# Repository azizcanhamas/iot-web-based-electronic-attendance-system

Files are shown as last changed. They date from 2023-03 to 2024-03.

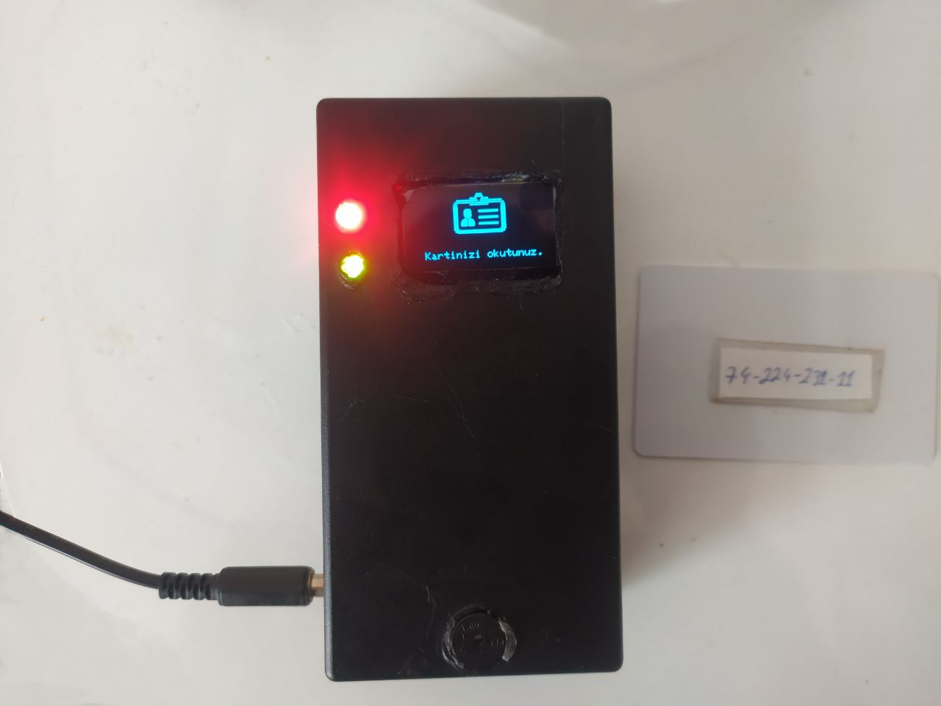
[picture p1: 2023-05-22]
report/interim_report/images/outer.png

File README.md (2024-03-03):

# IoT & Web Based Electronic Attendance System
Firat University Computer Engineering graduation project. 

# YouTube Video
https://www.youtube.com/watch?v=eulfiEd6Mw8

# Login screen.
login

# Student panel for attendance tracking.
student

# Admin panel for system management.
admin

# Circuit diagram for device.
circuit

# Database diagram.
db

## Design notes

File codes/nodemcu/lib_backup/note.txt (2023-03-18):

* Klasörler "Documents -> Arduino -> libraries" 
dizinine kopyalanmalıdır.

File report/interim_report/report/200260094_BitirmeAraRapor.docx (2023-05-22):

T.C.

FIRAT ÜNİVERSİTESİ

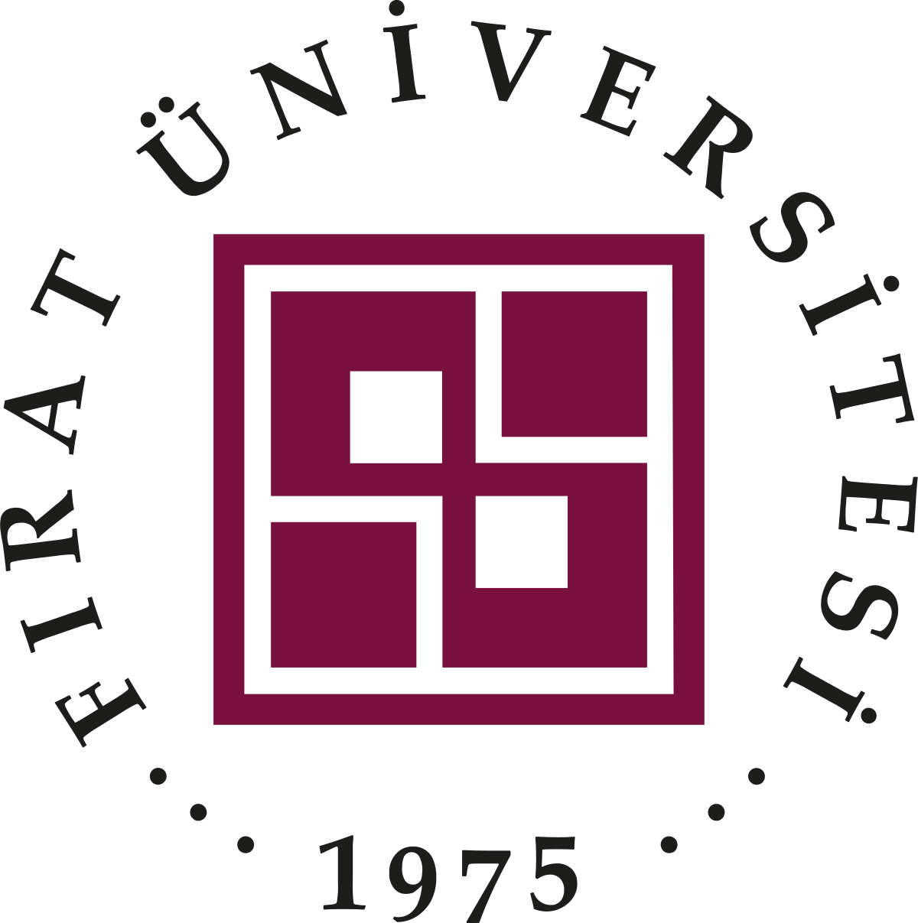
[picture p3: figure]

IoT TABANLI

ELEKTRONİK YOKLAMA SİSTEMİ

BİTİRME PROJESİ

ARA RAPORU

Aziz Can HAMAŞOĞLU

Danışman: Dr. Öğr. Üyesi Erkan DUMAN

# İÇİNDEKİLER

# GİRİŞ

Fırat Üniversitesi Bilgisayar Mühendisliği Lisans programından mezun olabilme şartı olan Bitirme Projesi dersi için “IoT Tabanlı Elektronik Yoklama Sistemi” konulu proje bahar yarıyılının başında proje konusu olarak seçilmişti. Bu raporda projenin hangi aşamaya getirildiği, hangi özelliklerin kazandırıldığı, bu özelliklerin geliştirilmesi için hangi teknolojilerin kullanıldığı, projede hangi eksikliklerin mevcut olduğu ve bu eksikliklerin nasıl giderileceğine değinilmiştir. Detaylı teknik açıklamalara yazılması planlanan bitirme tezinde değinilecektir.

## 1. Elektronik Yoklama Süreci

Şekil 1’de elektronik yoklama sürecinin nasıl gerçekleştirildiği adım adım gösterilmiştir. 1 numaralı adımda; derse katılan öğrenci sistemde kendisine tanımlanan RFID kartını cihaza okutmaktadır. Cihaz tarafından okutulan RFID kartının değerleri okunmaktadır. Elde edilen bu değerler kurumun Wi-Fi ağına bağlı olan mikrodenetleyici kart ile sunucuya API servisleri üzerinden gönderilmektedir. Sunucu, hangi IoT cihazının istekte bulunduğu, gelen RFID bilgisi ile öğrencinin kayıtlı olup olmadığı, ilgili dersi alıp almadığı gibi kompleks kontrolleri veritabanına bağlanarak gerçekleştirmektedir. Gerçekleştirilen bu kontroller sonucunda öğrenciye “Yoklama Alındı!”, “Kart Tanımlı Değil!”, “Bu Derse Kayıtlı Değilsiniz!” gibi bilgilendirici mesajlar ekranda gösterilmektedir.

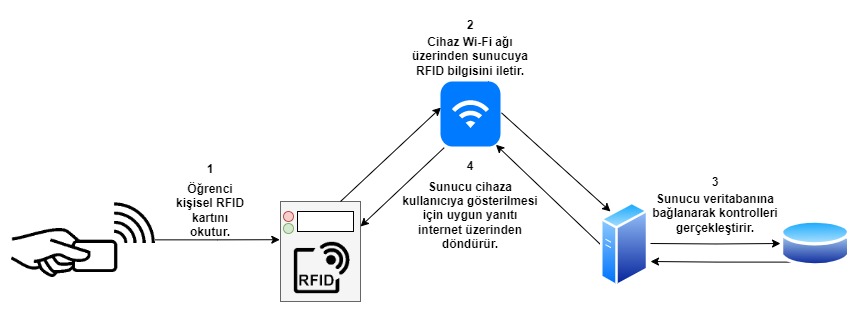
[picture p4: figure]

Şekil 1: Elektronik yoklama sürecini gösterir akış diyagramı

## 2. Donanım Kısmının Gerçekleştirilmesi

Öğrencilerin kullanacak olduğu RFID kartlarının okunabilmesi, bu kartlardan okunan değerlerin sunucuya internet üzerinden iletilebilmesi ve öğrenciye bilgilendirme mesajlarının gösterilebilmesi için bir donanım çözümü geliştirilmiştir. Bu donanım çözümü için geliştirilen devre diyagramına Şekil 2’de yer verilmiştir.

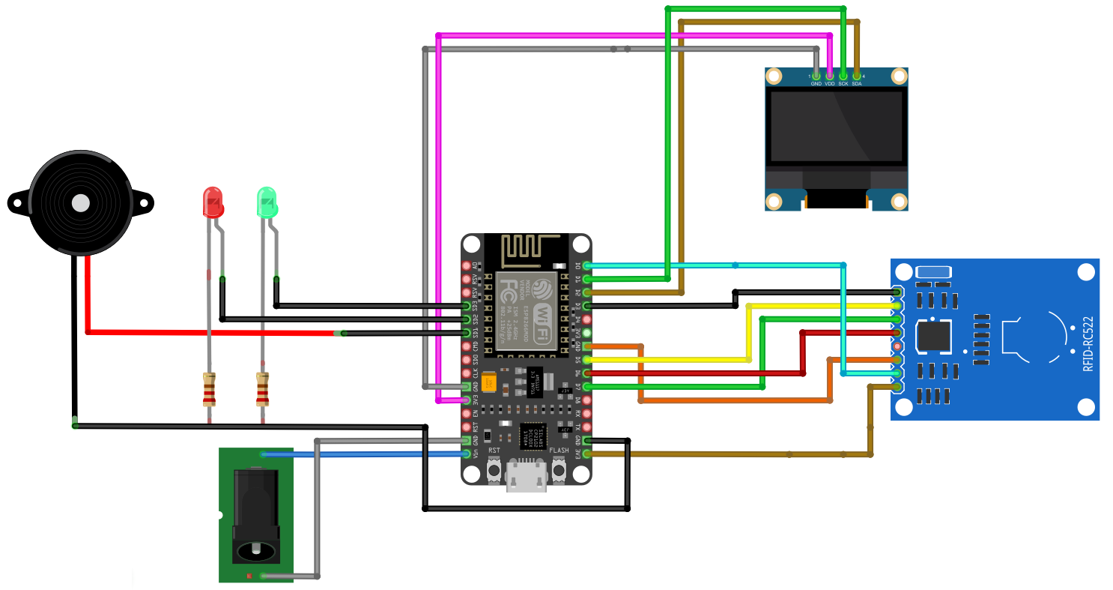
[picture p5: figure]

Şekil 2: Donanım çözümü için geliştirilen devreye ait diyagram

Devrede mikrodenetleyici olarak üzerinde ESP8266 Wi-Fi modülünü bulundurmması açısından NodeMCU kartı kullanılmıştır. NodeMCU geliştirme kartı, üzerinde CH340 çipini barındırmaktadır. Az alan kaplaması, projede kullanılacak olan çevre birimleri ile haberleşebilecek pin sayısına sahip olması ve UART, SPI, I2C gibi haberleşme protokollerini desteklemesinden dolayı projede kullanılması uygun görülmüştür. Kart 5V voltaj gerilimi ile beslenmiştir ve tüm çevre birimleri çalışabilmeleri için gerekli olan enerjiyi bu kart üzerinden almaktadır.

Devrede öğrenciye sesli ve ışıklı geri bildirim sunulabilmesi için Buzzer, bir adet 5mm kırmızı LED, bir adet 5mm yeşil LED kullanılmıştır. Sunucudan olumsuz bir yanıt geldiği zaman Buzzer uzun bir ses çıkarmakta ve kırmızı LED yanmaktadır. Öğrencinin yoklaması başarılı bir şekilde alındığı taktirde Buzzer iki kısa “bip” sesi çıkarmakta ve yeşil Led yanmaktadır. Bu 3 donanım, geliştirme kartına dijital pinler üzerinden bağlanmıştır. LED’lerin aşırı akımdan korunması için 330 Ω(Ohm) değerinde LED’lerin GND bacağına dirençler eklenmiştir.

Geliştirme kartının portatif bir şekilde beslenebilmesi için devreye DC Power Barrel Jack eklenmiştir. Bu güç girişi geliştirme kartının Vin ve GND pinlerine bağlanmıştır. Geliştirme kartının tavsiye edilen voltaj gerilimi 5V ve 3.3V olduğundan dolayı bu girişten 5V gerilimi uygulanmaktadır.

RFID kart modülü olarak RC522 isimli kit kullanılmıştır. Bu kitte bir adet RFID Reader ve iki adet RFID kartı bulunmaktadır. Bu kartların biri kredi kartı formunda diğeri anahtarlık formundadır. Her kartın kendine özgü bir hexadecimal değeri bulunmaktadır. RFID Reader, üzerindeki mikrokontrolcü ile haberleşilebilmesi için SS, SCK, MOSI, MISO, RST isimil pinler bulundurmaktadır. SS, SCK, MOSI, MISO pinleri SPI haberleşmesi için kullanılmıştır. Bu modül 3.3V voltaj gerilimi ile çalışması gerektiğinden, modülün enerji ihtiyacı geliştirme kartında bulunan 3.3V pininden karşılanmıştır.

Öğrenciye okunabilir geri bildirim sunulabilmesi için OLED ekran kullanılmıştır. Bu ekran üzerinde öğrenciye logolar ve sunucudan dönen yanıtlar gösterilmektedir. Mikrokontrolcü kart ile ekranın haberleşmesi için I2C protokolü kullanılmıştır ve ekran 3.3V voltaj gerilimi ile beslenmiştir.

## 3. Donanımın Kutulanması

Geliştirilen donanımın toz, sıvı teması, kısa devre gibi dış etkenlerden korunması için geliştirilen devre kutulanmıştır. Maliyetin düşük olması, arzu edildiği gibi müdahale edilebilmesi için plastik kutu kullanılması tercih edilmiştir. Bunun için Altınkaya firmasına ait PR-120 isimli kutu tercih edilmiştir. Kutu plastik malzemeden üretilmiş olup 68x130x44mm ölçülerindedir. Kutu, gereksiz alan kaplamayacak şekilde devrenin tamamını muhafaza etmiştir. Gerçekleştirilen bu aşama ile donanım kısmı tamamlanmıştır. Donanımın son durumu Şekil 3 görselinde gösterilmiştir.

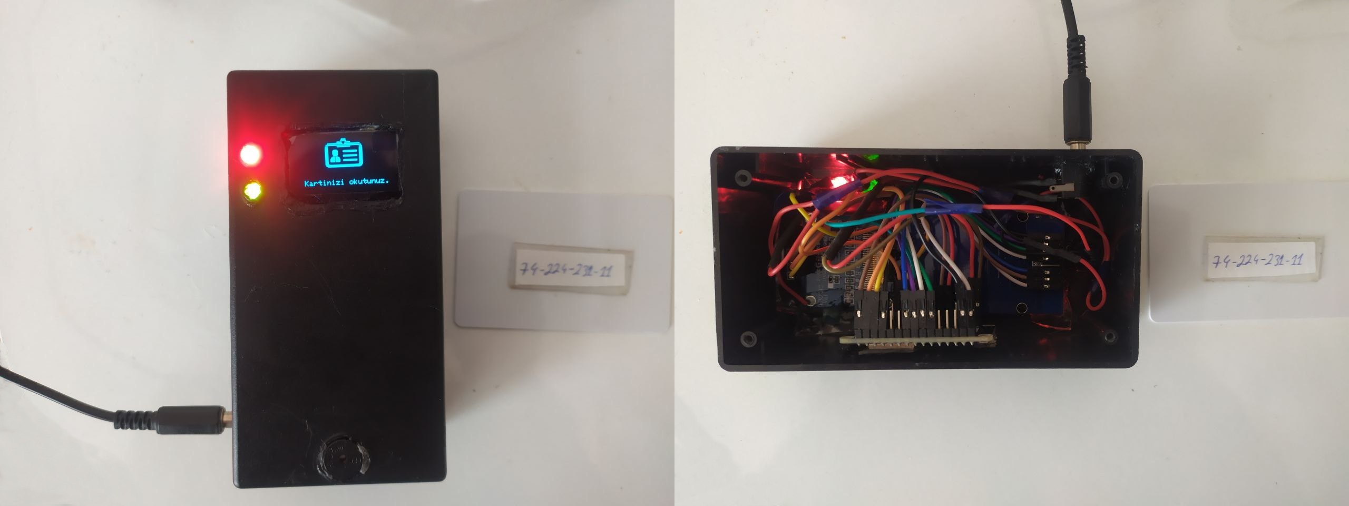
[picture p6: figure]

Şekil 3: Donanım çözümü olarak geliştirilen cihaz

## 4. Gömülü Yazılımın Gerçekleştirilmesi

Geliştirme kartının çevre birimlerini sürebilmesi, sunucu ile haberleşebilmesi için gömülü yazılım geliştirilmiştir. Bu yazılım Arduino IDE üzerinde Arduino mimarisini kullanarak geliştirilmiştir.

Yazılımda OLED ekranın sürülebilmesi, yazı ve logoların gösterilebilmesi için Adafruit GFX, Adafruit SH110X, Wire kütüphanelerinden yararlanılmıştır. NodeMCU geliştirme kartı üzerinde bulunan ESP8266 WiFi modülünün kullanılabilmesi için ESP8266WiFi kütüphanesinden yararlanılmıştır. Sunucu tarafından cihaza geri döndürülen JSON yanıtlarının ayrıştırılabilmesi (parse) için ArduinoJson kütüphanesi kullanılmıştır. RFID Reader ile haberleşilebilmesi için RC522 modülü için geliştirilmiş olan MFRC522 kütüphanesi kullanılmıştır.

OLED ekranda öğrenciye logoların gösterilebilmesi için görseller birtakım işlemlerden geçirilmiştir. Öncelikle logolar transparan forma fotoğraf düzenleyicileri araçlar aracılığıyla dönüştürülmüştür. Ardından https://javl.github.io/image2cpp/ adresindeki ByteArray dönüştürücü aracı kullanılarak bitmap dizileri oluşturulmuştur. Bu sayede logolar öğrenciye OLED ekranda başarıyla gösterilmiştir. Sunucudan olumsuz bir yanıt geldiği takdirde öğrenciye bir “X” logosu, olumlu bir yanıt geldiğinde “✓” logosu gösterilmektedir.

Cihaz sonsuz (loop) durumunda iken bir öğrencinin kart okutmasını beklemektedir. Bunu yanısıra belli periyotlarda cihazın bulunduğu sınıfta hangi dersin işlendiğini ekranda gösterebilmek için sunucudan geçerli dersin adını talep etmektedir. Sunucudan geçerli dersin talep edilmesi ve ekranda gösterilmesi henüz gömülü yazılımda bulunan algoritmaya entegre edilmemiştir. İlerleyen süreçte bu geliştirme yapılacaktır.

## 5. Sunucu Yazılımının Gerçekleştirilmesi

Sınıflarda bulunan cihazlardan gelen isteklerin işlenebilmesi, bir bölüme ait derslerin, öğrenciler ve akademisyenler ile ilgili veritabanı işlemlerinin gerçekleştirilebilmesi, öğrencilerin devamsızlıklarını takip edebileceği ve sistem yöneticisinin gerekli işlemleri gerçekleştirilebileceği panellerin geliştirilmesi için sunucu taraflı bir yazılıma ihtiyaç duyulmuştur. Bu yazılım Java dilinde Spring Boot Framework’ü kullanılarak geliştirilmiştir. Panellerin ön yüz (front-end) kısmı HTML,CSS,Bootstrap kullanılarak geliştirilmiştir.

Sistem iki adet panel içermektedir. Bir panel öğrenciler için diğer panel sistem yöneticisi için geliştirilmiştir. Bu panellere yalnızca yetkisi olanların erişebilmesi için bir adet de giriş paneli oluşturulmuştur. Giriş kontrolleri Spring Security ile yapılan yapılandırmalar sayesinde gerçekleştirilmektedir. Bu giriş paneline Şekil 4’de yer verilmiştir.

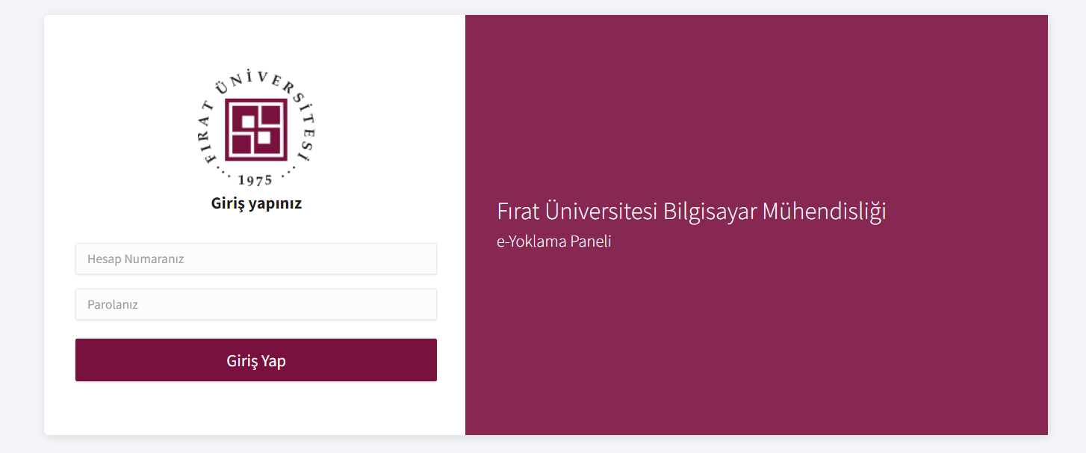
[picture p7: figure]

Şekil 4: Tarayıcı üzerinden erişilen e-Yoklama sistemine giriş paneli

Öğrencilerin devamsızlıklarını takip edebileceği panele Şekil 5 görselinde yer verilmiştir. Bu panelde öğrencinin almış olduğu dersler otomatik olarak listelenmekte ve her derse devamsızlık bilgisi veritabanında çekilerek gösterilmektedir. “Profil” sayfasında öğrenciye ait TCKN, sınıf, ad-soyad, doğum tarihi, doğum yeri bilgileri yine veritabanında çekilerek gösterilmektedir.

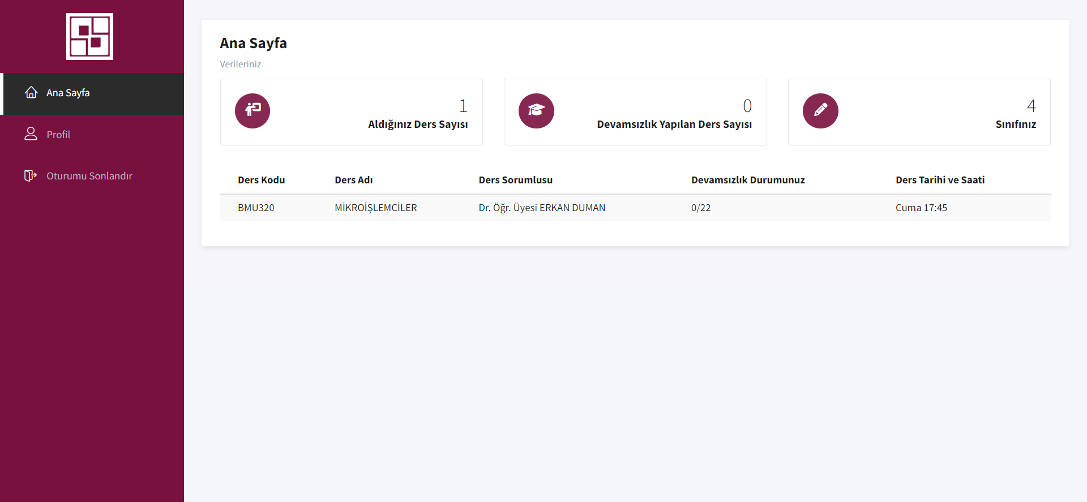
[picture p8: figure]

Şekil 5: Öğrenci paneli görünümü

Sistemde ADMIN (Yönetici) rolünde tanımlı bir kişi bulunmaktadır. Bu kişi veritabanına müdahale edebilen tek kullanıcıdır. Bu kullanıcı sisteme öğrenci ve akademisyenleri ekleyebilir, silebilir, sorgulayabilir ve tanımlı bilgileri güncelleyebilir. Bunun yanında yoklaması alınmış bir derste “YOK” yazılmış bir öğrenciyi “VAR” yazabilir veya tam tersini yapabilir. Ayrıca sisteme yeni dersler, sınıflar tanımlayabilir veya bu sınıflara öğrencilerin kartlarını okuyacak olan cihazları tanımlayabilir. Yönetici panelinin görünümüne Şekil 6’da ve örnek olması açısından yöneticiye ait “Ders İşlemleri” paneline ait panel Şekil 7’de gösterilmiştir.

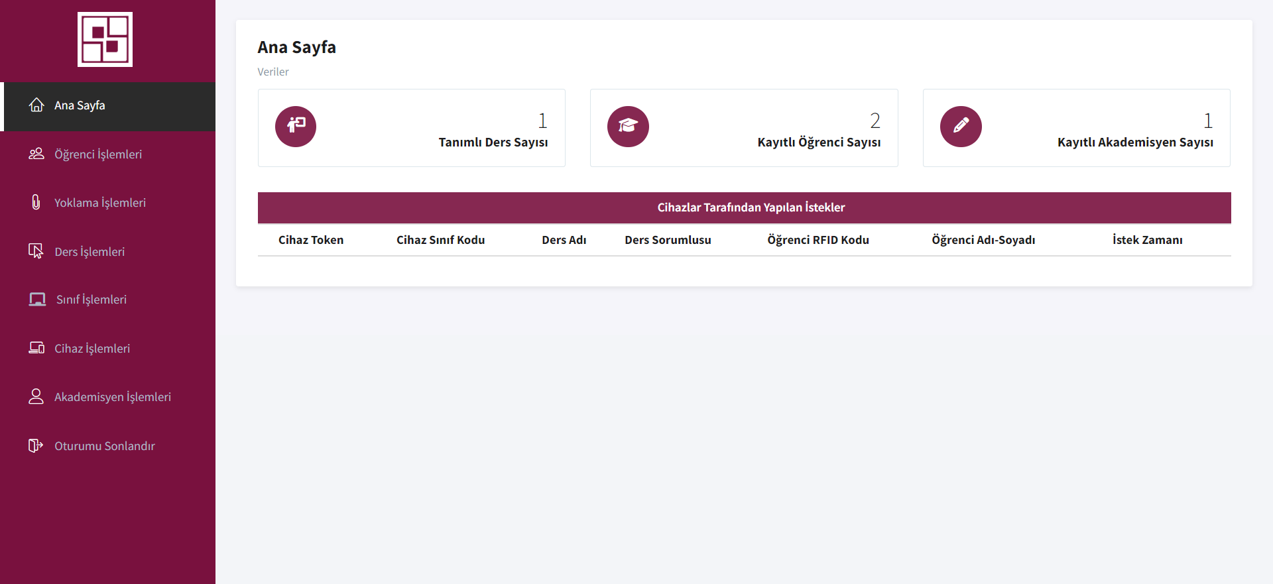
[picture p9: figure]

Şekil 6: Yönetici paneli görünümü

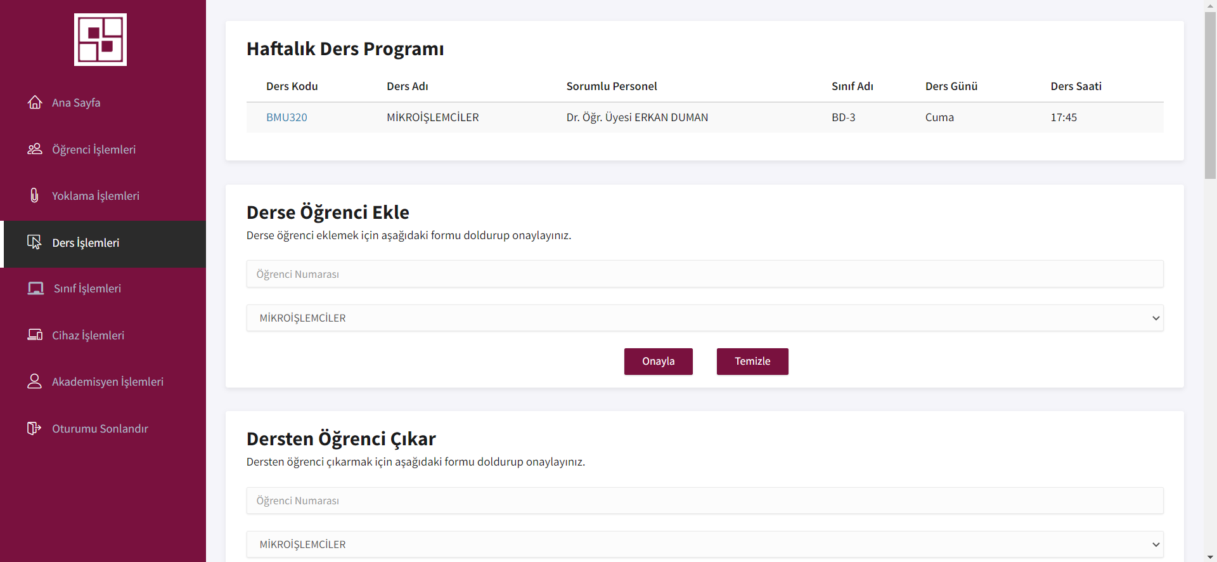
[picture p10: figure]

Şekil 7: Yönetici panelinde bulunan “Ders İşlemleri” paneli görünümü

Tüm kayıtların veritabanında saklanması için veritabanı mimarisi geliştirilmiştir. Bu mimariye Şekil 8’de yer verilmiştir. User tablosu öğrencilerin ve ADMIN kişisinin panellere girişinde parola ve rol kontrollerinin gerçekleştirildiği tablodur. Bu tabloda parolalara BCrypt algoritması ile şifrelenerek saklanmaktadır.

Bundan dolayı parolalar kötü niyetli kişiler tarafından çalınsa dahi hiçbir anlam ifade etmeyecektir. Ogrenci ve Akademisyen tablolarında öğrencilerin ve akademisyenlerin kişisel bilgileri tutulmaktadır. Yoklama tablosunda işlenen her derse ait yoklama kayıtları tutulmaktadır. DersOgrencileri tablosu, bir derse kayıtlı olan öğrencilerin bulunabilmesi için oluşturulmuştur. Cihaz tablosu her sinifta olan cihazın sisteme kayıtlı olup olmadığını sorgulamak için kullanılır.

CihazIstekleri tablosu cihazlardan gelen isteklerin planlı bir şekilde işlenmesi için oluşturulmuştur. Bu tablo sayesinde bir dersin yoklaması ders başladıktan belli bir süre sonra kapatılabilmektedir. Bunun için sunucu tarafında zaman planlamalı bir görev atanmıştır.

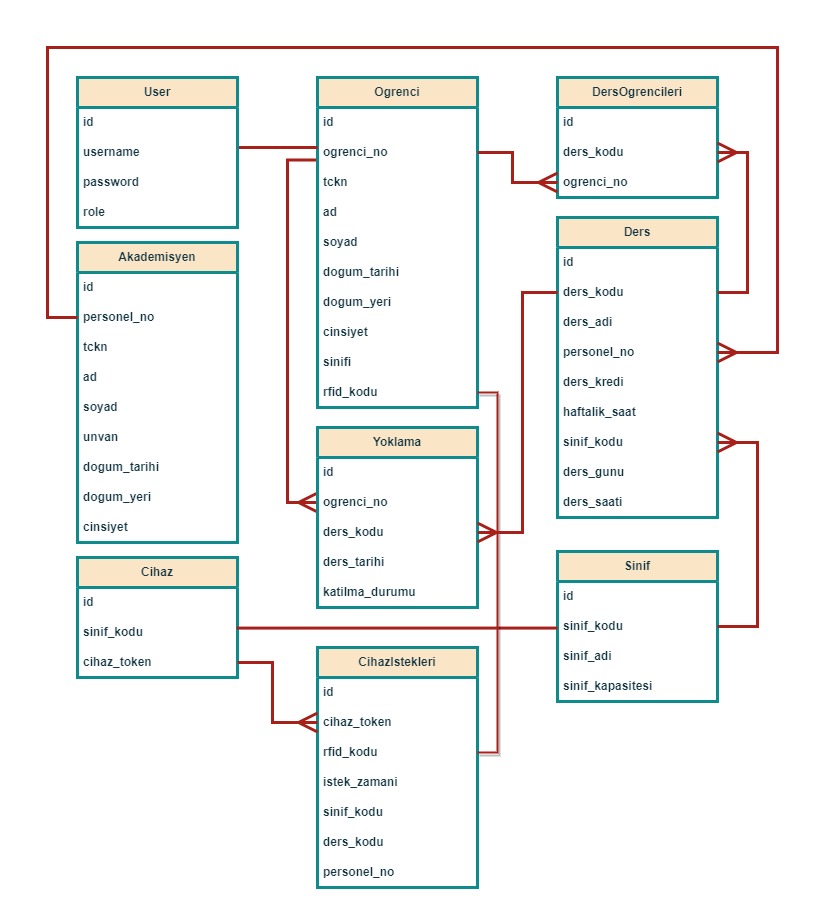
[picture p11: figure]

Şekil 8: Veritabanı mimarisi

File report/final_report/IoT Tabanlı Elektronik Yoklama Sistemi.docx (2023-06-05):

T.C.

FIRAT ÜNİVERSİTESİ

MÜHENDİSLİK FAKÜLTESİ

BİLGİSAYAR MÜHENDİSLİĞİ BÖLÜMÜ

IoT TABANLI ELEKTRONİK YOKLAMA SİSTEMİ GELİŞTİRİLMESİ

Aziz Can HAMAŞOĞLU

Tez Danışmanı

Dr. Öğr. Üyesi ERKAN DUMAN

BİTİRME TEZİ

BİLGİSAYAR MÜHENDİSLİĞİ BÖLÜMÜ

ELAZIĞ - 2023

T.C.

FIRAT ÜNİVERSİTESİ

MÜHENDİSLİK FAKÜLTESİ

BİLGİSAYAR MÜHENDİSLİĞİ BÖLÜMÜ

IoT TABANLI ELEKTRONİK YOKLAMA SİSTEMİ GELİŞTİRİLMESİ

Aziz Can HAMAŞOĞLU

BİTİRME TEZİ

BİLGİSAYAR MÜHENDİSLİĞİ BÖLÜMÜ

Bu bitirme tezi ...../...../2023 tarihinde, aşağıda belirtilen jüri tarafından oybirliği/oyçokluğu ile başarılı/başarısız olarak değerlendirilmiştir.

(İmza) Danışman | (İmza) Üye | (İmza) Üye

ÖZGÜNLÜK BİLDİRİMİ

Bu çalışmada, başka kaynaklardan yapılan tüm alıntıların, ilgili kaynaklar referans gösterilerek açıkça belirtildiğini, alıntılar dışındaki bölümlerin, özellikle projenin ana konusunu oluşturan teorik çalışmaların ve yazılım/donanımın benim tarafımdan yapıldığını bildiririm.

Fırat Üniversitesi 22.05.2023

Bilgisayar Mühendisliği Aziz Can HAMAŞOĞLU

23119 Elazığ

BENZERLİK BİLDİRİMİ

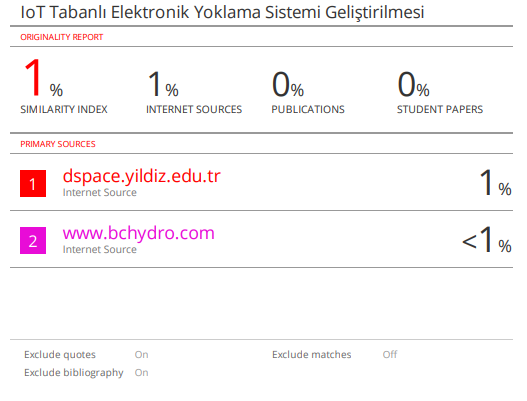
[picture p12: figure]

TEŞEKKÜR

Gömülü sistemler hakkında derslerde pratiğe yönelik bilgiler veren başta danışman hocam Dr. Öğr. Üyesi Erkan DUMAN olmak üzere, sektörün içerisinde “Kıdemli Yazılım Mühendisi” ünvanıyla yer alan ve Web mimarileri hakkında değerli bilgilerini benimle paylaşan sevgili Metin BAĞCI’ya teşekkür ve saygılarımı sunarım.

Yazılımı bana öğreten ve elindeki tüm imkanları bana sunan sevgili babam Hasan HAMAŞOĞLU’ya, beni büyütüp yetiştiren sevgili annem Nide HAMAŞOĞLU’ya sonsuz teşekkür ederim.

# İÇİNDEKİLER

# ŞEKİLLER LİSTESİ

Tablo 2.1: Kullanılan teknolojiler ve kullanım amaçları

Şekil 3.1: Elektronik yoklama sürecini gösterir akış diyagramı

Şekil 4.1: Donanım çözümü için geliştirilen devreye ait diyagram

Şekil 5.1: Cihazın dış görünümü

Şekil 5.2: Cihazın iç görünümü

Şekil 7.1: Giriş paneli için yapılan Spring Security yapılandırmaları

Şekil 7.2: Tarayıcı üzerinden erişilen e-Yoklama sistemine giriş paneli

Şekil 7.3: Parolanın şifrelenmesini gösterir diyagram

Şekil 7.4: Öğrenci paneli görünümü

Şekil 7.5: Bir öğrenciye ait bilgileri güncelleyen fonksiyon

Şekil 7.6: Yönetici paneli ana sayfası

Şekil 7.7: “Öğrenci İşlemleri” paneli

Şekil 7.8: “Yoklama İşlemleri” paneli

Şekil 7.9: “Ders İşlemleri” paneli

Şekil 7.10: “Sınıf İşlemleri” paneli

Şekil 7.11: “Cihaz İşlemleri” paneli

Şekil 7.12: “Akademisyen İşlemleri” paneli

Şekil 8.1: Veritabanı mimarisi

Şekil 9.1: DersOgrencileri tablosuna ait Entity sınıfı

Şekil 9.2: DersOgrencileri tablosuna ait Repository arayüzü

Şekil 10.1: Yoklama kapatma işlemi için uygulanan algoritma

# KISALTMALAR LİSTESİ

RFID : Radio Frequency Identification

API : Application Programming Interface

Wi-Fi : Wireless Fidelity

IoT : Internet of Things

UART : Universal Asynchronous Receiver Transmitter

SPI : Serial Peripheral Interface

I2C : Inter-Integrated Circuit

V : Volt

LED : Light Emitting Diode

GND : Ground

Vin : Voltage Input

DC : Direct Current

SS : Slave Select

SCK : Serial Clock

MOSI : Master Out Slave In

MISO : Master In Slave Out

RST : Reset

OLED : Organic Light Emitting Device

IDE : Integrated Development Environment

JSON : Javascript Object Notation

HTML : Hyper Text Markup Language

CSS : Cascading Style Sheets

TCKN : Türkiye Cumhuriyeti Kimlik Numarası

ORM : Object Relational Mapping

OOP : Object Oriented Programming

REST : Representational State Transfer

GIMP : GNU Image Manipulation Program

# ÖZET

Günümüzde kağıt üzerinde gerçekleştirilen klasik işlemlerin dijital dönüşüm uygulamaları ile elektronik ortama taşınması sayesinde veriye dünyanın her yerinden güvenli ve kontrollü bir şekilde erişim sağlanabilmektedir [1]. Eğitim-öğretim kurumlarında öğrencilerin derslere olan devamının kontrolünü sağlayan yoklama uygulamasının dijital dönüşümü için bu proje çözüm olarak geliştirilmiştir. Tez kapsamında; bir öğrencinin dijital olarak nasıl kimliklendirilebileceği, kurum sınıflarında gerçekleştirilen derslerin yoklamasının planlı bir şekilde nasıl alındığı ve öğrencilerin devam durumlarını kontrol edebileceği panellerin nasıl oluşturulduğu, sistemi organize eden yöneticiye ait panelin geliştirilmesi konularına açıklık getirilmiştir.

# ABSTRACT

Today, thanks to the digital transformation applications of classical processes carried out on paper, it can be accessed in a safe and controlled manner from all over the world. This project has been developed as a solution for the digital transformation of the polling practice, which provides control of students' attendance to courses in educational and educational institutions. Within the scope of the thesis; how a student can be digitally identified, how the take of the courses held in the institution classes is planned and how the panels are created where the students can check their attendance status, The issues of developing the panel of the manager organizing the system were clarified.

## 1. GİRİŞ

Teknolojinin gelişmesiyle klasik yöntemlerle gerçekleştirilen evrak işlemleri dijital dönüşüm sayesinde elektronik ortama taşınabilmektedir. Bu dönüşüm sonucunda süreçler daha hızlı, daha esnek ve daha güvenilir şekilde yönetilebilmektedir. Dijital ortamda tutulan verilere dünyanın her yerinden ulaşılabilmesi ve bu verilerin kolay yedeklenebilir olmasından dolayı dünyadaki tüm kamu ve özel sektör kurumları dijital dönüşümü var gücüyle gerçekleştirmektedir. Bunun yanı sıra elektronik sistemler tarafından yapılan kontroller sayesinde insan hatası en aza indirilmekte ve bilgisayarların sahip olduğu yüksek işlem gücü sayesinde zamandan tasarruf edilmektedir.

“Nesnelerin İnterneti (IoT)” konsepti dijital dönüşümün önemli bir parçasıdır. Bu konsept sayesinde bilgiye erişim dünya çapında gerçekleştirilebilmektedir [2]. Bir kurum, bir bölge içerisinde ve hatta dünya üzerinde dağılmış olan küçük ölçekli sistemler, “Nesnelerin İnterneti” sayesinde kendi aralarında haberleşebilir ve daha yüksek işlem gücüne sahip olan sunucular ile iletişim kurabilir [3]. Kurumlar, bu esnek mimari sayesinde ihtiyaç duyduğu ortam ve kullanıcı etkileşimli operasyonların tamamında istenilen ölçekte sistem kurgulayabilmektedir.

Gerçekleştirilmiş olan bu projede; eğitim-öğretim kurumlarında öğrencilerin derslere olan devamının kontrolünü sağlayan ve bir çizelge üzerinde gerçekleştirilen yoklama uygulamasının dijital dönüşümü “Nesnelerin İnterneti” konsepti sayesinde gerçekleştirilmiştir.

## 2. KULLANILAN TEKNOLOJİLER VE PROGRAMLAR

Donanım ve yazılım çözümlerinin geliştirilmesi sırasında kullanılan teknolojiler, programlar, kütüphaneler ve geliştirme ortamlarına kullanım amaçları ile Tablo 2.1’de yer verilmiştir.

Teknoloji | Kullanım Amacı
Github | Projenin geliştirilmesi aşamasında uzak sunucuda yedeklenmesi ve kaynak kodlarının yönetilmesi
GIMP | OLED için logoların yeniden boyutlandırılması ve transparan hale getirilmesi
Java 11 | Sunucu taraflı yazılımın geliştirilmesi
PHPMyAdmin | MySQL veritabanı sunucusunun grafiksel arayüz ile yönetilmesi
MySQL | Depolanması gereken tüm kayıtlar için veritabanı yönetim sistemi
Apache Tomcat | Panellerden ve cihazlardan gelen HTTP isteklerinin kabul edilmesi
Postman | API uç noktalarının test edilmesi
Intellij Idea | Sunucu taraflı yazılım için geliştirme ortamı olarak kullanılması
Spring Boot | Yazılım iskeleti olarak kullanılması
Spring Security | Kullanıcıların oturumlandırılması ve yetkilendirilmesi
Hibernate ORM | Nesne-İlişkisel Eşleme yöntemiyle verilerin veritabanında nesneler olarak tutulması
Thymeleaf | HTML sayfalarının dinamikleştirilmesi
HTML, CSS, Bootstrap | Panellerin ön yüz tasarımının gerçekleştirilmesi
REST API | Sunucu tarafındaki API uç noktalarının oluşturulması
Arduino IDE | Gömülü yazılım geliştirme için geliştirme ortamı
Fritzing | Cihazlara ait devre tasarımının gerçekleştirilmesi
image2cpp | OLED ekranda resim gösterebilmek için resimlerin ByteArray’e dönüştürülmesi

Tablo 2.1: Kullanılan teknolojiler ve kullanım amaçları

## 3. ELEKTRONİK YOKLAMA SÜRECİ

Bir derse katılan öğrencinin sistem tarafından tanınabilmesi ve bu öğrenci ile ilgili kaydın oluşturulabilmesi için Şekil 3.1’de gösterildiği gibi elektronik yoklama süreci kurgulanmıştır ve nasıl gerçekleştirildiği adım adım gösterilmiştir. 1 numaralı adımda; derse katılan öğrenci sistemde kendisine tanımlanan RFID kartını sınıfta sabit olarak bulunan cihaza okutmaktadır. Okutulan RFID kartına ait değerler kurumun Wi-Fi ağına bağlı olan cihaz tarafından sunucuya API servisleri üzerinden gönderilmektedir. Bu gönderme işlemi sırasında parametre olarak cihazın hangi sınıfta olduğunu tanımlayan bir token de gönderilmektedir. Bu sayede sunucu, hangi sınıftaki cihazın yoklama isteğinde bulunduğunu anlayabilmektedir. Sunucu cihazdan gelen RFID bilgisi ile öğrencinin kurumda kayıtlı olup olmadığı, ilgili dersi alıp almadığı ve o sınıfta ders işlenip işlenmediği gibi kompleks kontrolleri veritabanına bağlanarak gerçekleştirmektedir. Gerçekleştirilen bu kontroller sonucunda eğer herhangi bir olumsuz durum yoksa sunucu tarafından cihaza “Yoklama Alındı!” mesajı yanıt olarak gönderilmekte ve öğrenciye OLED ekranda gösterilmektedir. Eğer olumsuz bir durum varsa o duruma ait mesaj aynı şekilde cihaza gönderilerek ekranda gösterilmektedir.


Şekil 3.1: Elektronik yoklama sürecini gösterir akış diyagramı

## 4. DONANIM KISMININ GERÇEKLEŞTİRİLMESİ

Öğrencilerin kullanacak olduğu RFID kartlarının okunabilmesi, bu kartlardan okunan değerlerin sunucuya internet üzerinden iletilebilmesi ve öğrenciye bilgilendirme mesajlarının gösterilebilmesi için bir donanım çözümü geliştirilmiştir. Bu donanım çözümü için Fritzing ortamında geliştirilen devre diyagramına Şekil 4.1’de yer verilmiştir.


Şekil 4.1: Donanım çözümü için geliştirilen devreye ait diyagram

### 4.1. Geliştirme Kartı

Devrede mikrodenetleyici olarak üzerinde ESP8266 Wi-Fi modülünü bulundurması açısından NodeMCU kartı kullanılmıştır. NodeMCU geliştirme kartı, üzerinde CH340 çipini barındırmaktadır. Az alan kaplaması, projede kullanılacak olan çevre birimleri ile haberleşebilmek için yeterli pin sayısına sahip olması ve UART, SPI, I2C gibi haberleşme protokollerini desteklemesinden dolayı bu kartın projede kullanılması uygun görülmüştür. Kart 5V voltaj gerilimi ile beslenmiştir ve tüm çevre birimleri çalışabilmeleri için gerekli olan enerjiyi bu kart üzerinden almaktadır.

### 4.2. Görsel ve Sesli Geri Bildirimler

Devrede öğrenciye sesli ve ışıklı geri bildirim sunulabilmesi için Buzzer, bir adet 5mm kırmızı LED, bir adet 5mm yeşil LED kullanılmıştır. Sunucudan olumsuz bir yanıt geldiği zaman Buzzer uzun bir ses çıkarmakta ve kırmızı LED yanmaktadır. Öğrencinin yoklaması başarılı bir şekilde alındığı taktirde Buzzer iki kısa “bip” sesi çıkarmakta ve yeşil LED yanmaktadır. Bu 3 donanım, geliştirme kartına dijital pinler üzerinden bağlanmıştır. LED’lerin aşırı akımdan korunması için LED’lerin GND bacağına 330 Ω(Ohm) değerinde dirençler eklenmiştir.

Öğrenciye okunabilir geri bildirim sunulabilmesi için OLED ekran kullanılmıştır. Bu ekran üzerinde öğrenciye logolar ve sunucudan dönen yanıtlar gösterilmektedir. Mikrodenetleyici kart ile ekranın haberleşmesi için I2C protokolü kullanılmıştır ve ekran 3.3V voltaj gerilimi ile beslenmiştir.

### 4.3. Besleme Portu

Geliştirme kartının portatif bir şekilde beslenebilmesi için devreye DC Power Barrel Jack eklenmiştir. Bu güç girişi geliştirme kartının Vin ve GND pinlerine bağlanmıştır. Geliştirme kartının beslenmesi için tavsiye edilen voltaj gerilimi 5V-3.3V aralığında olduğundan dolayı bu girişten 5V gerilimi uygulanmaktadır.

### 4.4. Fiziksel Kimliklendirme

Öğrencilerin fiziksel olarak kimliklendirilmesi için RFID teknolojisinden yararlanılmıştır. Bunun için “RC522 RFID” isimli kit kullanılmıştır. Bu kitte bir adet RFID kart okuyucu ve iki adet RFID kartı bulunmaktadır. Bu kartların biri kredi kartı formunda diğeri anahtarlık formundadır. Her kartın kendine özgü bir hexadecimal değeri bulunmaktadır. RFID kart okuyucunun üzerindeki mikrodenetleyici ile haberleşilebilmesi için board üzerinde SS, SCK, MOSI, MISO, RST isimli pinler bulundurmaktadır. SS, SCK, MOSI, MISO pinleri SPI haberleşmesi için kullanılmıştır. Bu modülün 3.3V voltaj gerilimi ile beslenmesi gerektiğinden, modülün enerji ihtiyacı geliştirme kartında bulunan 3.3V pininden karşılanmıştır.

## 5. DONANIMIN KUTULANMASI

Geliştirilen donanım; toz, sıvı teması, kısa devre gibi dış etkenlerden korunması için kutulanmıştır. Maliyetin düşük olması ve arzu edildiği gibi formuna müdahale edilebilmesi açısından plastik kutu kullanılması tercih edilmiştir. Bunun için Altınkaya firmasına ait PR-120 isimli kutu tercih edilmiştir. Kutu plastik malzemeden üretilmiş olup 68x130x44mm ölçülerindedir. Kutu, gereksiz alan kaplamayacak şekilde devrenin tamamını muhafaza etmiştir. Kullanıcı ile etkileşimi sağlayacak olan LED, Buzzer ve OLED ekran, kutudan delikler açılarak dışarıya çıkartılmıştır. Devrenin adaptörden beslenebilmesi için DC Barrel Jack kutunun yan tarafından dışarıya çıkarılmıştır. Kutu içerisinde kalacak olan NodeMCU ve RFID kart okuyucu çift taraflı bant ile sabitlenmiştir. Plastik kutunun malzemesinin yeterli derecede ince olmasından dolayı RFID kart okuyucu sorunsuz bir şekilde RFID kartlarının değerlerini okuyabilmektedir. Fritzing üzerinde gerçekleştirilmesi planlanan devre başarıyla hayata geçirilmiştir. Donanımın son durumu Şekil 5.1 görselinde gösterilmiştir.

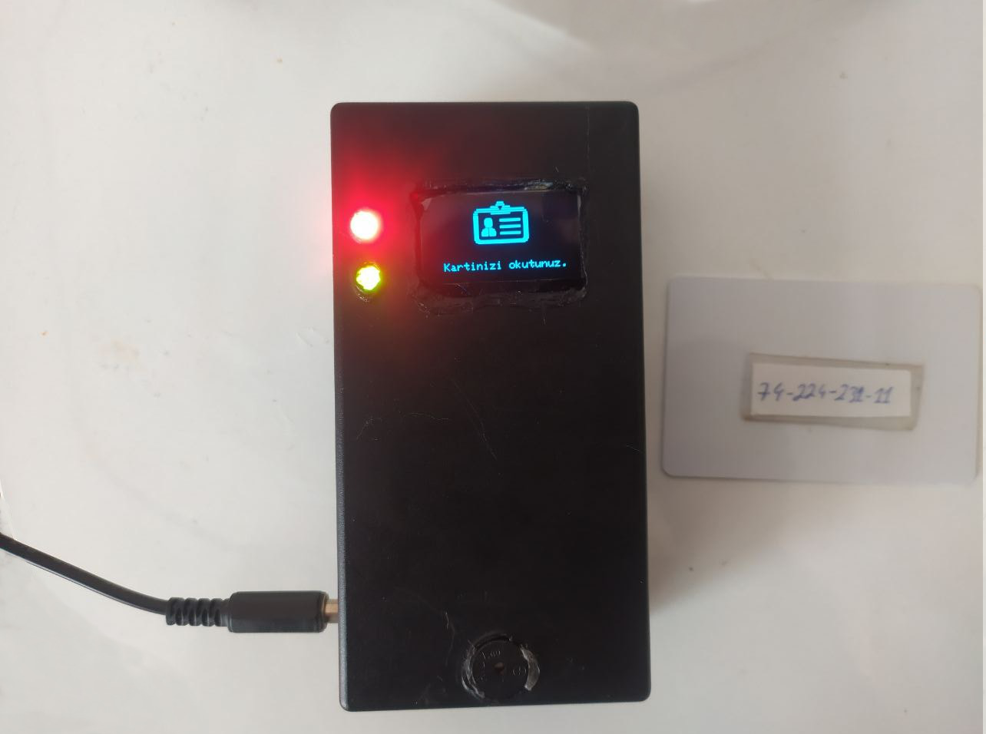
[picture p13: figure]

Şekil 5.1: Cihazın dış görünümü

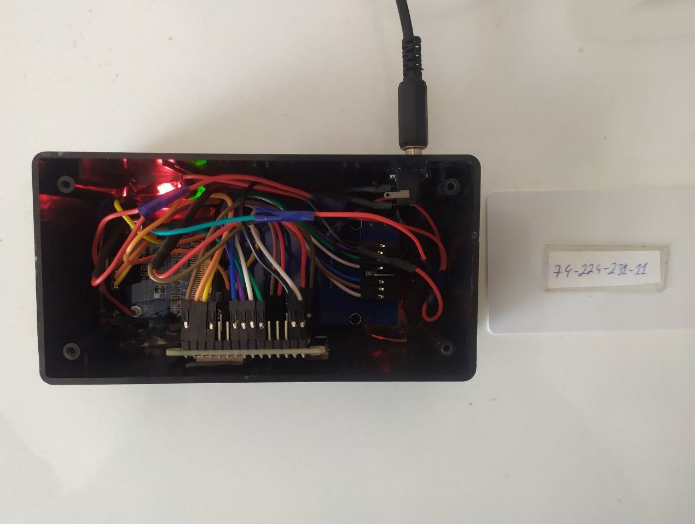
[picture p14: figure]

Şekil 5.2: Cihazın iç görünümü

## 6. GÖMÜLÜ YAZILIMIN GERÇEKLEŞTİRİLMESİ

Geliştirme kartının çevre birimlerini sürebilmesi ve sunucu ile haberleşebilmesi için gömülü yazılım geliştirilmiştir. Bu yazılım Arduino IDE üzerinde Arduino mimarisini kullanarak geliştirilmiştir.

### 6.1. Gömülü Yazılım İçin Kullanılan Kütüphaneler

Yazılımda OLED ekranın sürülebilmesi, yazı ve logoların gösterilebilmesi için Adafruit GFX, Adafruit SH110X ve Wire kütüphanelerinden yararlanılmıştır. NodeMCU geliştirme kartı üzerinde bulunan ESP8266 WiFi modülünün kullanılabilmesi için ESP8266WiFi kütüphanesinden yararlanılmıştır. Sunucu tarafından cihaza geri döndürülen JSON yanıtlarının ayrıştırılabilmesi (parse) için ArduinoJson kütüphanesi kullanılmıştır. RFID kart okuyucu ile haberleşilebilmesi için RC522 modülü için geliştirilmiş olan MFRC522 kütüphanesi kullanılmıştır.

### 6.2. OLED Ekranın Gömülü Yazılım İle Sürülmesi

OLED ekranda öğrenciye logoların gösterilebilmesi için görseller birtakım işlemlerden geçirilmiştir. Öncelikle logolar GIMP fotoğraf düzenleme aracıyla transparan forma dönüştürülmüştür. Ardından https://javl.github.io/image2cpp/ adresindeki image-byteArray dönüştürücü aracı kullanılarak bitmap dizileri oluşturulmuştur. Bu sayede logolar öğrenciye OLED ekranda başarıyla gösterilmiştir. Sunucudan olumsuz bir yanıt geldiği takdirde öğrenciye bir “X” logosu, olumlu bir yanıt geldiğinde “✓” logosu ve sunucudan gelen mesaj öğrenciye gösterilmektedir.

### 6.3. RFID Kartların Okunması

Öğrencilerin yoklama işlemi için okutmuş olduğu RFID kartlara ait değerlerin gömülü yazılım tarafına alınması için sonsuz döngü içerisinde birtakım kontroller gerçekleştirilmiştir. Cihaz sürekli olarak yeni bir kartın basılıp basılmadığını bir if() kontrolü içerisinde denetlemektedir. Eğer bu koşul gerçekleşirse karta ait seri değerler bir Byte dizisine aktarılır ve sunucuya gönderilmesi için ilgili fonksiyonlara yönlendirilir.

### 6.4. Uzak Sunucuya Cihaz Tarafından Bağlanılması

NodeMCU mikrodenetleyicisinin sunucuya bağlanabilmesi için üzerinde bulunan ESP8266 Wi-Fi modülünün internet bağlantısı gerçekleştirilmiştir. Bunun için ESP8266WiFi kütüphanesinden yararlanılmıştır. Cihaz, kaynak kodunda belirtilen Wi-Fi ağına bağlantı gerçekleştirdikten sonra yoklama isteklerini uzak sunucunun IP adresine veya domain adresine HTTP protokolü ile göndermektedir.

## 7. SUNUCU YAZILIMININ GERÇEKLEŞTİRİLMESİ

Sınıflarda bulunan cihazlardan gelen isteklerin işlenebilmesi, bir bölüme ait dersler, öğrenciler ve akademisyenler ile ilgili veritabanı işlemlerinin gerçekleştirilebilmesi, öğrencilerin devamsızlıklarını panel üzerinden takip edebilmesi ve sistem yöneticisinin gerekli işlemleri panel üzerinden gerçekleştirebilmesi için sunucu taraflı bir yazılıma ihtiyaç duyulmuştur. Bu yazılım Java dilinde Spring Boot Framework’ü kullanılarak geliştirilmiştir. Panellerin ön yüz (front-end) kısmı HTML,CSS,Bootstrap kullanılarak geliştirilmiştir.

### 7.1. Veri Güvenliğinin Sağlanması

Sistem iki adet panel içermektedir. Bir panel öğrenciler için diğer panel sistem yöneticisi için geliştirilmiştir. Bu panellere yalnızca yetkisi olanların erişebilmesi için bir adet de giriş paneli oluşturulmuştur. Giriş kontrolleri Spring Security ile yapılan yapılandırmalar sayesinde gerçekleştirilmektedir. Bu güvenlik yapılandırmalarına Şekil 7.1’de yer verilmiştir. Giriş panelinin tasarımına Şekil 7.2’de yer verilmiştir.

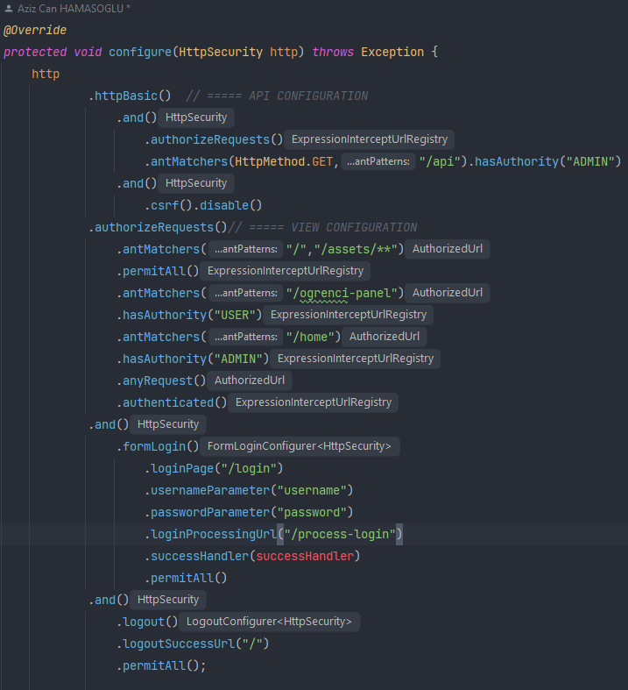
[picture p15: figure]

Şekil 7.1: Giriş paneli için yapılan Spring Security yapılandırmaları


Şekil 7.2: Tarayıcı üzerinden erişilen e-Yoklama sistemine giriş paneli

Yeni bir kayıt öğrenci kaydı oluşturulduğu zaman kayıt işleminde önce kullanıcının girmiş olduğu parola, BCrypt algoritması ile hash fonksiyonu uygulanarak veritabanında saklanmaktadır. Bundan dolayı veritabanında tutulan parolalar kötü niyetli kişiler tarafından çalınsa dahi hiçbir anlam ifade etmeyecektir. BCrypt algoritmasına ait fonksiyonlar Spring Boot tarafından varsayılan olarak sağlanmaktadır. BCrypt algoritması ile veri şifrelemeyi gösterir blok diyagramına Şekil 8.2’de yer verilmiştir.

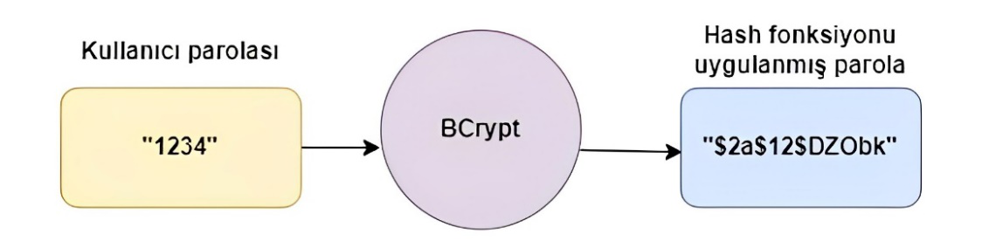
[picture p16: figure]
hash (1)

Şekil 7.3: Parolanın şifrelenmesini gösterir diyagram

### 7.2 Öğrenci Paneli

Öğrencilerin devamsızlıklarını takip edebileceği panele Şekil 7.3 görselinde yer verilmiştir. Bu panelde öğrencinin almış olduğu dersler otomatik olarak listelenmekte ve öğrencinin kayıtlı olduğu her derse ait devamsızlık bilgisi veritabanından çekilerek gösterilmektedir. “Profil” sayfasında öğrenciye ait TCKN, sınıf, ad-soyad, doğum tarihi, doğum yeri bilgileri yine veritabanından çekilerek gösterilmektedir.


Şekil 7.4: Öğrenci paneli görünümü

### 7.3 Yönetici Paneli

Sistemde ADMIN (Yönetici) rolünde tanımlı bir kişi bulunmaktadır. Bu kişi sistemde tutulan kayıtlara ve sistem yapısına müdahale edebilen tek kullanıcıdır. Bu kullanıcı sisteme öğrenci ve akademisyenleri ekleyebilir, silebilir, sorgulayabilir ve kişilere ait bilgileri güncelleyebilir. Bunun yanında yoklaması alınmış bir derste “YOK” yazılmış bir öğrenciyi “VAR” yazabilir veya tam tersini yapabilir. Ayrıca sisteme yeni dersler, sınıflar tanımlayabilir veya bu sınıflara öğrencilerin kartlarını okuyacak olan cihazları tanımlayabilir. Spring Boot tarafında her panel için bir Controller sınıfı oluşturulmuş ve her Controller sınıfı içerisinde ekleme, güncelleme, silme, sorgulama ve diğer spesifik işlemler için fonksiyonlar tanımlanmıştır. Bu fonksiyonlara belirli URL adresleri ve uygun parametreler ile ulaşılabilmektedir. Örnek olması açısından Şekil 7.4’de bir öğrenciye ait bilgileri güncelleyen fonksiyona ait kaynak kod verilmiştir.

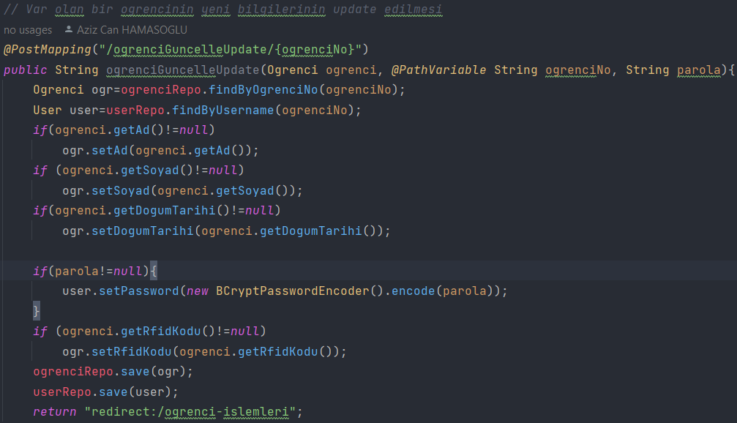
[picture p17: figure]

Şekil 7.5: Bir öğrenciye ait bilgileri güncelleyen fonksiyon

Yönetici panelinde bulunan ana sayfanın görünümüne Şekil 7.5’de, “Öğrenci İşlemleri” paneline Şekil 7.6’de, “Yoklama İşlemleri” paneline Şekil 7.7’da, “Ders İşlemleri” paneline Şekil 7.8’de, “Sınıf İşlemleri” paneline Şekil 7.9’de, “Cihaz İşlemleri” paneline Şekil 7.10’da, “Akademisyen İşlemleri” paneline Şekil 7.11’da yer verilmiştir.


Şekil 7.6: Yönetici paneli ana sayfası

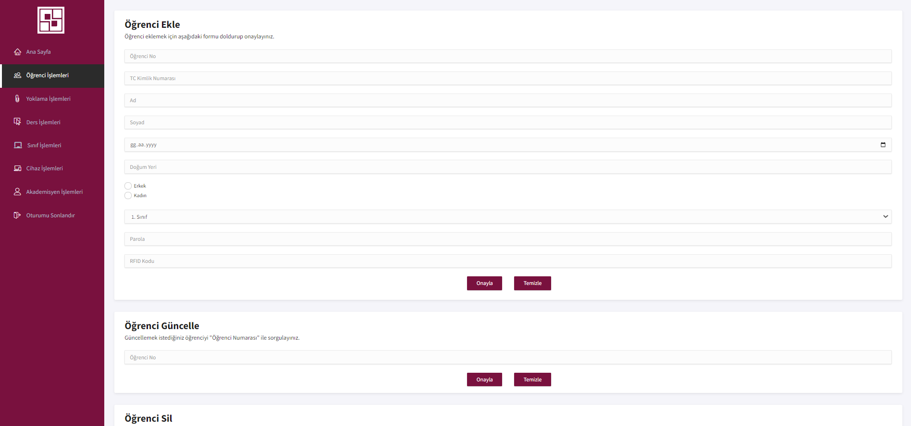
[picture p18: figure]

Şekil 7.7: “Öğrenci İşlemleri” paneli

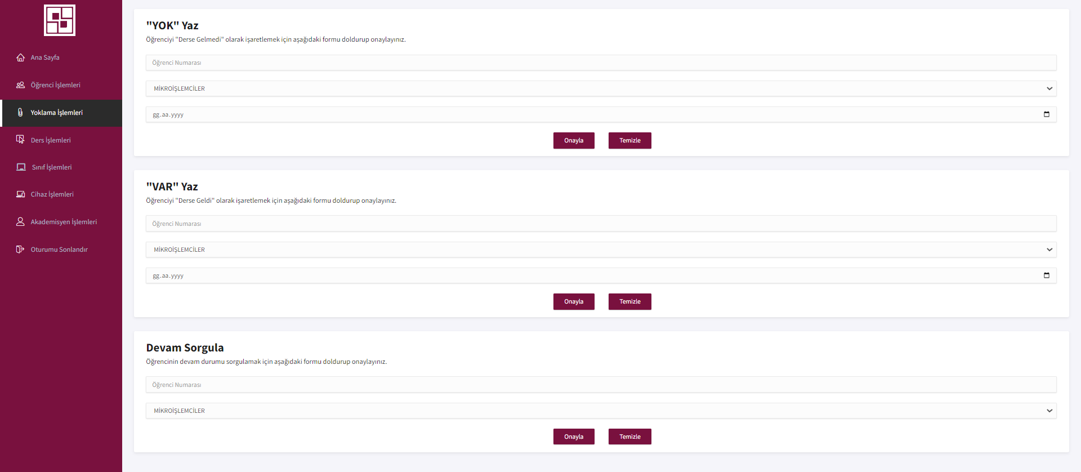
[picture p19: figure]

Şekil 7.8: “Yoklama İşlemleri” paneli

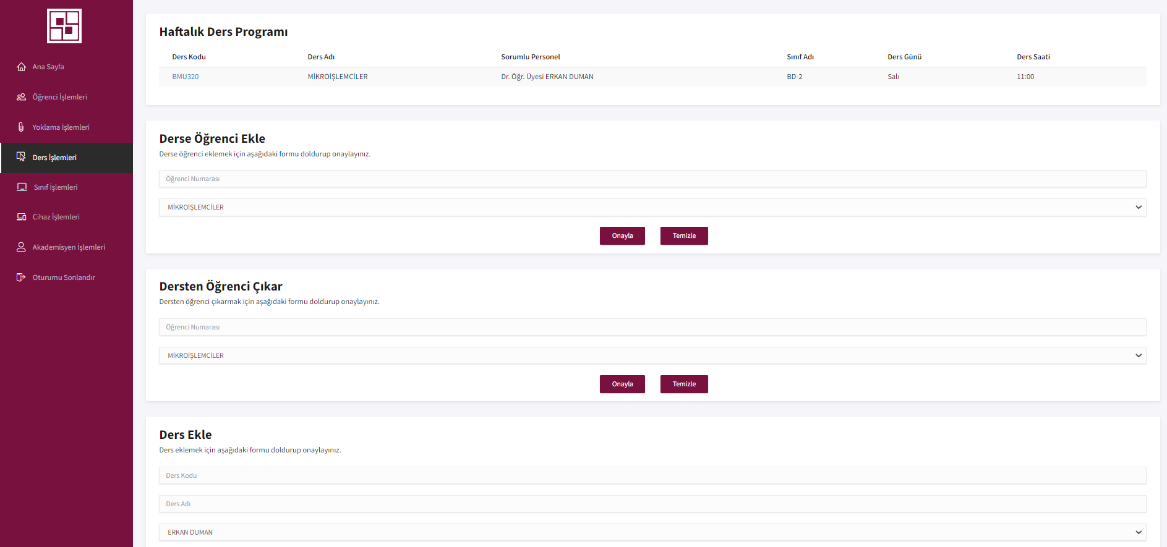
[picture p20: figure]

Şekil 7.9: “Ders İşlemleri” paneli

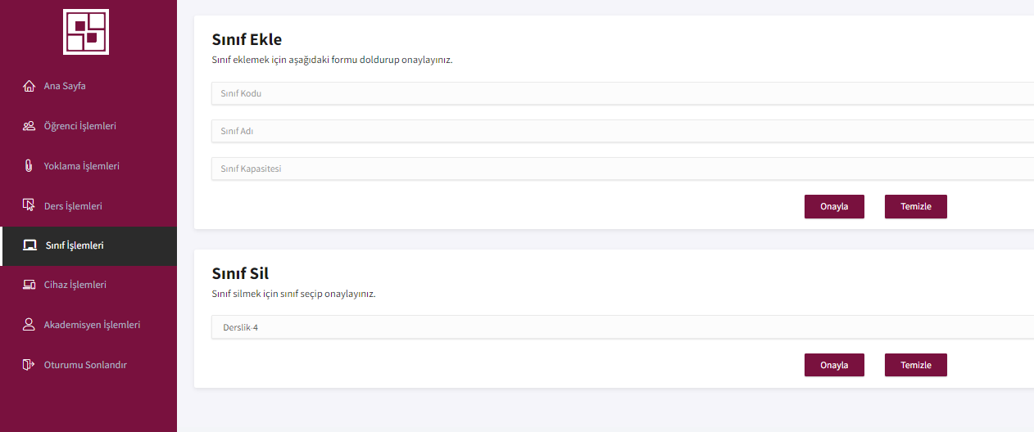
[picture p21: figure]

Şekil 7.10: “Sınıf İşlemleri” paneli

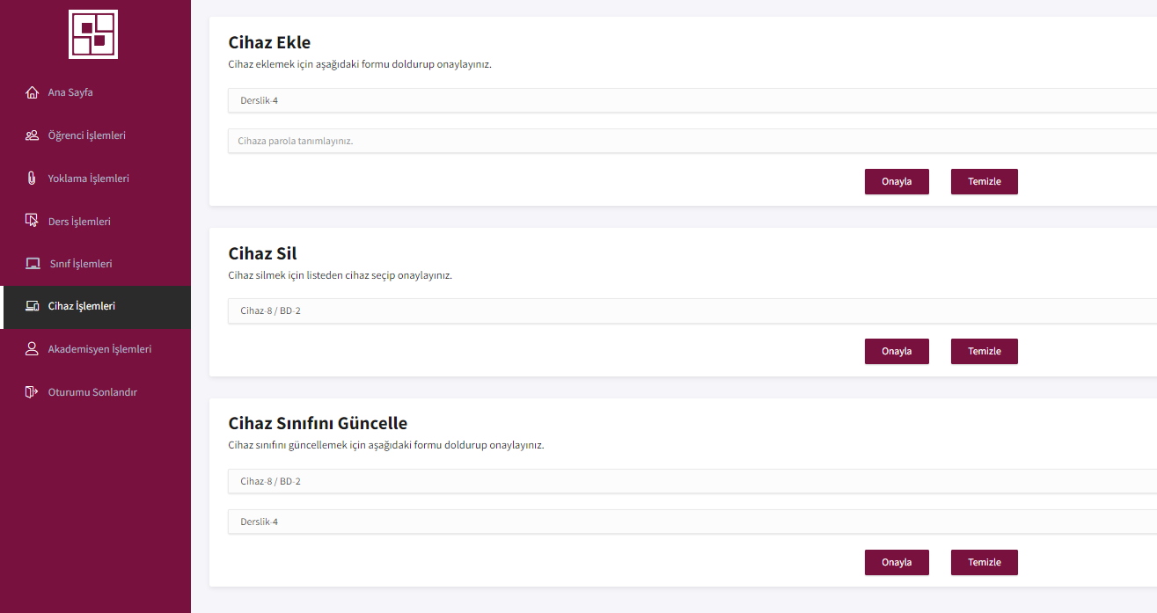
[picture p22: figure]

Şekil 7.11: “Cihaz İşlemleri” paneli

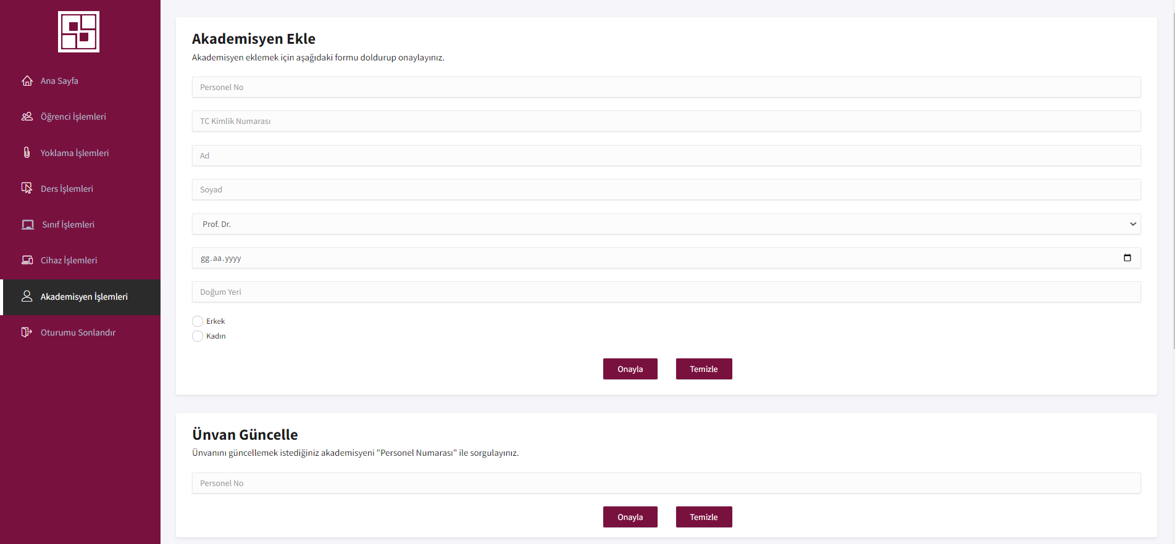
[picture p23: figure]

Şekil 7.12: “Akademisyen İşlemleri” paneli

## 8. VERİTABANI MİMARİSİNİN OLUŞTURULMASI

Tüm kayıtların veritabanında düzenli bir şekilde saklanabilmesi için veritabanı mimarisi geliştirilmiştir. Bu mimariye Şekil 8.1’de yer verilmiştir. User tablosu öğrencilerin ve sistem yöneticisinin panellere girişinde parola ve rol kontrollerinin gerçekleştirildiği tablodur. Öğrenciler USER rolü ile tanımlı olduğundan yönetici paneline erişimlerine izin verilmemektedir. Spring Security yapılandırmasında yalnızca ADMIN rolüne sahip olanların yönetici paneline erişmesine izin verileceği tanımlandığından öğrenciler yönetici paneline erişememektedir.

Ogrenci ve Akademisyen tablolarında öğrencilerin ve akademisyenlerin kişisel bilgileri tutulmaktadır. Yoklama tablosunda işlenen her derse ait yoklama kayıtları tutulmaktadır. DersOgrencileri tablosu, bir derse kayıtlı olan öğrencilerin bulunabilmesi için oluşturulmuştur. Cihaz tablosu her sinifta olan cihazın sisteme kayıtlı olup olmadığını sorgulamak için kullanılır.


Şekil 8.1: Veritabanı mimarisi

## 9. VERİTABANI İŞLEVLERİNİN TANIMLANMASI

Nesne ilişkisel eşleme (ORM) yapısı sayesinde sunucu taraflı yazılım geliştirmesinde daha az SQL kodu yazarak ve nesne yönelimli programlama (OOP) yaklaşımına daha uygun olacak şekilde geliştirme gerçekleştirilmiştir [4]. Spring Boot üzerinde Hibernate ile ORM yapısının oluşturulması için Entity ve Repository katmanları oluşturulmuştur.

### 9.1 Entity Katmanı

Entity katmanında her tabloyu niteleyecek birer sınıf (Class) oluşturulmuştur. Bu sınıflar içerisinde tablonun sütunlarını niteleyecek olan alan adları (field) oluşturulmuştur. Bu sınıflara verilen @Column anotasyonuyla tabloda oluşturulacak olan sütunun adı verilmiştir. Örnek olması açısından Şekil 9.1’de DersOgrencileri tablosuna ait Entity sınıfının kaynak kodu verilmiştir. Şekilde gösterildiği üzere DersOgrencileri tablosunda bulunan id, ders_kodu, ogrenci_no sütunları için DersOgrencileri isimli sınıfta alan adları “private” erişim belirleyicisi ile oluşturulmuştur. DersOgrencileri tablosunu niteleyen her nesneye ait alan adlarına diğer sınıflar tarafından erişilebilmesi için getter-setter metotlar public olarak oluşturulmuştur.

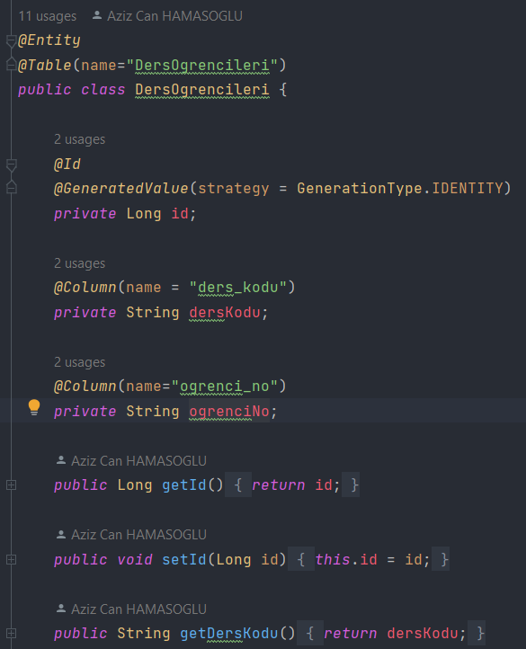
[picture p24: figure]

Şekil 9.1: DersOgrencileri tablosuna ait Entity sınıfı

### 9.2 Repository Katmanı

Veritabanı işlevlerinin tanımlanması için Repository katmanı oluşturulmuştur ve bu katman içerisinde her Entity sınıfı için birer arayüz (interface) oluşturulmuştur. Bu arayüzler JpaRepository arayüzünü kalıtım alarak bu arayüze ait fonksiyonları kullanabilmektedir. Bu fonksiyonlar save(), delete(), findAll() gibi hazır fonksiyonlardır. Bu fonksiyonlar sayesinde tablolar üzerinde kaydetme, silme, sorgulama gibi işlemler yapılabilmektedir. Bunun yanı sıra farklı amaçlara hizmet eden sorgular @Query anotasyonu ile oluşturulmuştur. Örnek olması açısından DersOgrencileri sınıfına ait Repository arayüzüne ait kaynak kodun bir kısmına Şekil 9.2’de yer verilmiştir. Repository katmanında bulunan yapılar arayüz olduğundan dolayı içerisinde gövdesiz metotlar tanımlanması gerekmektedir. Bu gövdesiz metotlar farklı amaçlara hizmet SQL sorgularının oluşturulmasında kullanılmıştır. Şekil 9.2’de gösterilen deleteByOgrenciNo() metodu bir derse kayıtlı olan öğrencinin silinmesi işlevini gerçekleştirmektedir. Bunun için ilgili öğrencinin numarasını ve ilgili dersin ders kodunu çağrıldığı sınıftan istemektedir. Bu metot silme işlemi gerçekleştirdiğinden dolayı herhangi bir hata oluşması durumunda sorgunun yarattığı etkinin geri alınabilmesi için @Modifying ve @Transactional anotasyonları bu metoda verilmiştir. DersOgrencileri tablosunda ilgili derse kayıtlı olan öğrencinin bulunup silinmesi işlevini gerçekleştiren sorgu @Query anotasyonu içerisinde String olarak verilmiştir.

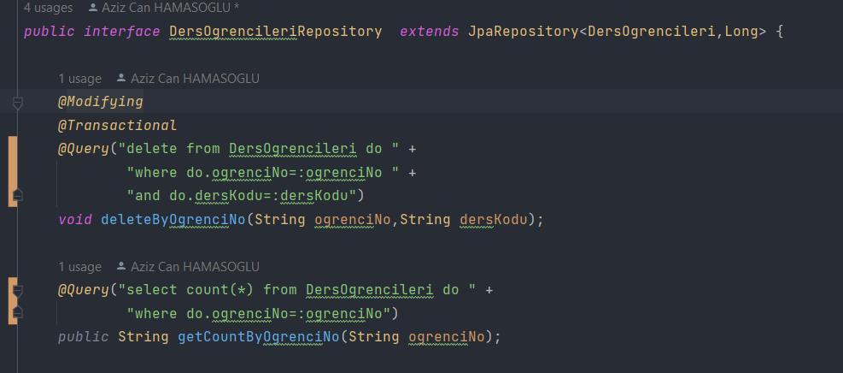
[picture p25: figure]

Şekil 9.2: DersOgrencileri tablosuna ait Repository arayüzü

## 10. PLANLI YOKLAMA GÖREVİNİN OLUŞTURULMASI

Bir ders başladıktan belli bir zaman sonra yoklama alma işleminin kapatılabilmesi için sunucu tarafında zaman planlamalı bir görev atanmıştır. Örneğin; ders başlama saatinden 15 dakika sonra öğrencinin yok yazılması. Bunun için kurumdaki her dersin (xx:00, xx:15, xx:30, xx:45) zamanlarında başladığı varsayılmıştır. Örnek bir senaryo düşünülecek olursa; Mikroişlemciler dersi 14:15’de başlamaktadır. Sunucuda zaman tetiklemeli bir görev tanımlandığı için saat 14:15 olduğunda dersin ilk 15 dakikasının dolup dolmadığına bakılacaktır. Dersin ilk 15 dakikası dolmadığından bir sonraki tetiklemenin gerçekleşeceği saat olan 14:30’da dersin yoklaması kapatılacaktır. Mikroişlemciler dersinin işlendiği sınıfta bulunan cihazdan 14:15-14:30 arasında gelen istekler “VAR” olarak işaretlenerek veritabanına kaydedilmektedir. Bu yaklaşım sayesinde sunucu sürekli olarak yeni bir dersin başlayıp başlamadığını kontrol etmek zorunda kalmayacak, gereksiz işlem yükü oluşmayacak ve veritabanı meşgul edilmemiş olacaktır.

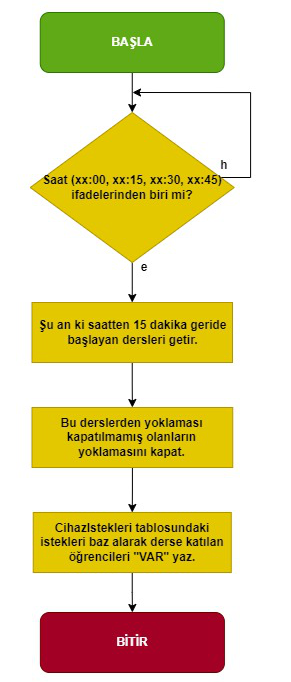
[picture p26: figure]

Şekil 10.1: Yoklama kapatma işlemi için uygulanan algoritma

## 11. SONUÇ

Yıllardır klasik olarak gerçekleştirilen işlemlerin dijital olarak dönüştürülmesi sayesinde bu işlemler daha hızlı, daha esnek ve daha az takip edilmesini gerektirecek şekilde gerçekleştirilebilmektedir. Dijital dönüşüm sayesinde insan üzerinde oluşan iş yükü kayda değer biçimde azaltılabilmekte ve işlemler otomatize edilebilmektedir. Geliştirilmiş olan bu proje sayesinde imza taklidi ve yoklama çizelgesinin kaybolması/kullanılamaz hale gelmesi/yanlış satıra imza atılması gibi insan kaynaklı olumsuz durumların önüne geçilmiş ve ders sorumlusu olan kişi üzerindeki iş yükü azaltılmıştır.

# KAYNAKLAR

[1] Türkiye’de Dijital Dönüşüm ve Girişimcilik, Abdullah BALLI (2021, Eylül 23)

[2] Nesnelerin İnterneti (IoT), Erdal Erdal , Atilla Ergüzen (2020, Ekim 19)

[3] Nesnelerin interneti. (2023, Nisan 20) İçinde Vikipedi. https://tr.wikipedia.org/wiki/Nesnelerin_interneti

[4] Object Relational Mapping (ORM) Nedir? (2017, Eylül 09) https://caylakyazilimci.com/post/object-relational-mapping-orm-nedir


# ÖZGEÇMİŞ

Aziz Can HAMAŞOĞLU

Telefon Numarası : +90 531 087 3509

E-posta: azizcanhamas@gmail.com

Eğitim: Fırat Üniversitesi, Mühendislik Fakültesi,

Bilgisayar Mühendisliği 4. Sınıf

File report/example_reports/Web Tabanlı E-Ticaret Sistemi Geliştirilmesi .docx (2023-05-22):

T.C.

FIRAT ÜNİVERSİTESİ

MÜHENDİSLİK FAKÜLTESİ

BİLGİSAYAR MÜHENDİSLİĞİ BÖLÜMÜ

WEB TABANLI E-TİCARET SİSTEMİ GELİŞTİRİLMESİ

Mehmet Fatih ŞURGUN

Tez Danışmanı

Prof. Dr. Galip AYDIN

BİTİRME TEZİ

BİLGİSAYAR MÜHENDİSLİĞİ BÖLÜMÜ

ELAZIĞ - 2022

T.C.

FIRAT ÜNİVERSİTESİ

MÜHENDİSLİK FAKÜLTESİ

BİLGİSAYAR MÜHENDİSLİĞİ BÖLÜMÜ

WEB TABANLI E-TİCARET SİSTEMİ GELİŞTİRİLMESİ

Mehmet Fatih ŞURGUN

BİTİRME TEZİ

BİLGİSAYAR MÜHENDİSLİĞİ BÖLÜMÜ

Bu bitirme tezi ….../……/2021 tarihinde, aşağıda belirtilen jüri tarafından oybirliği/oyçokluğu ile başarılı/başarısız olarak değerlendirilmiştir.

(İmza) Danışman | (İmza) Üye | | (İmza) Üye

ÖZGÜNLÜK BİLDİRİMİ

Bu çalışmada, başka kaynaklardan yapılan tüm alıntıların, ilgili kaynaklar referans gösterilerek açıkça belirtildiğini, alıntılar dışındaki bölümlerin, özellikle projenin ana konusunu oluşturan teorik çalışmaların ve yazılım/donanımın benim tarafımdan yapıldığını bildiririm.

Fırat Üniversitesi

27.05.2022

Bilgisayar Mühendisliği

23119 Elazığ Öğrencilerin Adı Soyadı

Mehmet Fatih ŞURGUN

BENZERLİK BİLDİRİMİ


TEŞEKKÜR

Projenin tüm aşamalarında bana yardım ve katkılarından dolayı değerli hocamız Prof.Dr. Galip AYDIN’a teşekkür ederim

İÇİNDEKİLER

Sayfa No

ŞEKİLLER LİSTESİ

Sayfa No

ÖZET

Günümüzde internet dünyasının gelişimiyle birlikte elektronik ticaret her anlamda kullanımı da artmış olup birlikte giyim sektörü üzerinde de satıcı ve alıcı için gerek fiyat gerek zaman açısından kolaylıklar sağlamıştır.

Elektronik ticaret sistemi yalnız ekonomik işlere katkı olarak görülmesinden ziyade, ekonomiden-teknolojiye, teknolojiden-sağlığa, sağlıktan-eğitime kadar geniş bir alanda topluma katkı sağlamıştır.

Bu çalışma kapsamında geliştirilen elektronik ticaret uygulaması Visual Studuio Code ortamında PHP programlama dili kullanılarak hazırlanmıştır. Uygulamada veritabanı işlemleri için MySQL kullanılmıştır.

ABSTRACT

Today, with the development of the internet world, the use of electronic commerce in every sense has increased and together with the clothing sector, it has provided convenience for the seller and buyer in terms of price and time.

Rather than the electronic commerce system being seen only as a contribution to economic activities, it has contributed to society in a wide range of areas from economy to technology, from technology to health, from health to education.

The electronic commerce application developed within the scope of this study has been prepared by using PHP programming language in Visual Studuio Code environment. In practice, MySQL is used for database operations.

1. GİRİŞ

Ticaret geçmişten günümüze kadar hayatımızın her yerini kapsamıştır. Ticaret kavramı kavramsal olarak “ürünün satın alınması ve satılması” işlemlerini kapsamaktadır. Bu dönemde internet dünyasının gelişimiyle birlikte ticaretin internet üzerinden yapılması elektronik ticaret kavramını ortaya çıkarmıştır.[1]

  1.1. Online Alışveriş Sistemi

Günümüzde teknolojik ve internet dünyasında ki hızlı değişimler ve gelişmelerle birlikte elektronik ticaret gelişim sağlamıştır. Yeni bir alışveriş, ihtiyaç gereksinim kanalı olarak nitelenen internet, alıcılara kolay bir şekilde alışveriş imkânı sağlamakta, yorulmadan mağaza mağaza gezmeden zamandan tasarruf sağlayarak alışveriş yapma imkânı sağlıyor.[2]

İnternette alışveriş süreci geleneksel alışverişten farklı olarak bilgisayar, tablet veya telefon üzerinden yapılmaktadır. Ek olarak ürün arama, ürün karşılaştırma, daha fazla çeşitlilik görme imkânı tanımaktadır. Bütün bu eylemler internet altyapısının getirmiş olduğu imkanlardır. Bilgisayarı olan insanlar için söz konusu işlemin ürün maliyet giderinin daha çok düşmesi internetin daha fazla önemini sağlamaktadır.[3]

  1.2. Online Alışveriş Sisteminin Avantajları
- Küçük işletmeler satış potansiyellerini yükseltebilirler.
- Bilgi akışı sürekli olarak devam eder.
- Hızlı bir şekilde sipariş verme olanağı vardır.
- Daha az maliyet vardır.
- Daha az giderle daha fazla reklam verme olanağı vardır.[4]
- Farklı ülke ve şehirlerde ki insanlara ulaşım imkânı sağlar
- Ürünlerin özelliklerini ve tanıtımlarını internet üzerinden gerçekleştirebilir.
- Daha rahat bir şekilde satış gerçekleştirebilir.[5]
  1.3. Sistem Modeli

MVC Model View Controller 3 ana bileşeninden oluşmaktadır. Kodumuzun bileşenlerini birbirinden ayırarak, kodu daha rahat bir şekilde geliştirilebilir hale getirmiş oluruz. Daha az hata çıkarma potansiyeline sahip olur.

Şekil 1.1. Sistem Modeli

Model

Veri tabanına erişim ve veri tabanı ilişkilerini sağlar. Yani veri işlemleri bu katmanda gerçekleşir. Entity Framework, Linq ve Ado.Net gibi Frameworkler bu katmanda işlem sağlar.

View

Bu katman kullanıcını gördüğü katmandır. Kısaca Front-End katmanı diyebiliriz. HTML, CSS ve Javascript gibi ara yüz teknolojileri bu katmanda kullanılır.

Controller

View ve model arasında kalan katmandır. Metotlar ve fonksiyonlar bu katmanda kullanılır. Kısaca kullanıcının view tarafında kullandığı komutların controller aracılığı ile model katmanına işlenmesini sağladığı katmandır.[6]

2. KULLANILAN TEKNOLOJİLERİN TANITIMI ve KURULUMU

2.1. Visual Studio Code

Visual Studio Code ücretsiz bir kaynak kod editörüdür. Microsoft tarafından geliştirilmiştir. Javascript ve Node.js için yerleşik bir şekilde gelir ve diğer kodlama dillerine destek verir. Kod tamamlama işlemi ve hatayı ayıklama gibi güçlü geliştirici özellikleri vardır.

Visual Studio Code’u internet sitesinden bilgisayarımızla uyumlu halini seçip indirme işlemini başlatıyoruz. Sonra programın yolunu seçip kurulum işlemini başlatıyoruz.


Şekil 2.1. Visual Studio Code Kurulum Ekranı

2.2. WAMP Server

Wamp Server Apache web sunucusunu, PHP programlama dilini, MySQL veri tabanı sunucusunu ve PhpMyAdmin veritabanı uygulamasını tek yerden yönetmemizi sağlayan paket programdır. Wamp Server web programcıları ve tasarımcıları için geliştirme ortamı sağlar. PHP ile yazılmış dinamik web sayfalarını localhost adresi üzerinden çalıştırmamızı sağlar. Wamp Server programını kurmak için önce web sitesine gidip indirme işlemini başlatıp kurulumunu yapıyoruz.

Şekil 2.2. WAMP Server Kurulum Ekranı

2.3. HTML, CSS ve JavaScript

HTML kısaca web sayfalarımızın iskeletidir. Web sayfalarını oluşturmak için kullanılan işaretleme dilidir. Öğrenmesi en basit işaretleme dilidir. HTML ile web sayfalarımızı şekillendirebiliriz.

CSS web sayfalarımızın görsel ve tasarım olarak şekillenmesini sağlayan bir tanım dilidir. CSS sayesinde renk ayarlarını, font ayarlarını ve görsel efektleri sağlayabiliriz. HTML bir web sayfasının iskeleti ise CSS o iskelet yapısının görsel ve tasarım bakımından güzel bir hal almasını sağlayan işaretleme dilidir.

Javascript internet sitelerini işlevsel hale getiren ve web sitelerinin fonksiyonlarını arttıran betik bir dildir. Javascript ile web sitelerini daha dinamik bir hale getirebiliriz.

2.4. jQuery

JQuery bir Javascript kütüphanesidir. Javascript ile uzun uzadıya kod yazacağımız yerde JQuery ile tek satır kod ile işlemlerimizi daha basit bir şekilde yapabiliyoruz. JQuery kütüphanesi Javascript ile kodlama yapmamızı kolaylaştırır.

2.5. Bootstrap

Bootstrap ön yüz geliştiricilerinin kullandığı popüler bir CSS ve Javascript kütüphanesidir. Bootstrap sayesinde tüm tarayıcılara uyumlu web sitelerini kolaylıkla geliştirebiliriz. Web projelerinin gelişimini hızlandırır. Kullanımı kola temel HTML ve CSS bilgisi ile web siteleri ve uygulamalar geliştirebiliriz. Tüm tarayıcıların ekran boyutlarına adapte olur.

2.6. PHP

PHP yaygın bir şekilde kullanılan web tabanlı, açık kaynak kodlu programlama dilidir. Özellikle web uygulamaları geliştirmek ve dinamik web sayfaları hazırlamak için kullanılır. PHP en çok web geliştirme alanında kullanılır. HTML dosyasına gömülebilme özelliği sayesindedir. Açık kaynaklı olması ve çok yönlü fonksiyonel özelliğinden dolayı yaygın bir şekilde kullanılır.

3. PROJENİN GERÇEKLEŞTİRME AŞAMALARI

3.1. Ana Sayfa Ekranı


Şekil 3.1. Ana Sayfa Ekranı


Şekil 3.2. Ana Sayfa Ekranı

Giriş ekranımızı Bootstrap ve JQuery kütüphanesini kullanarak tasarladım. Ürün resimlerimizi ve sayfa resimlerimizi veri tabanından çekiyorum.

Şekil 3.3. Ana Sayfa Kod Ekranı

Anasayfa ekranımızda slider işlemlerini JQuery sayesinde yapıyorum ve ana sayfa ekranında olan yeni ürünler kısmının resimlerini sliderda olan resimleri veri tabanından çekiyoruz. Ana sayfanın tasarımlarını CSS yardımıyla hallettim.

3.2. Üye Giriş Ekranı


Şekil 3.4. Üye Giriş Ekranı

Şekil 3.5. Üye Giriş Kod Ekranı

HTML, CSS ve PHP yardımıyla üye giriş formumuzu düzenledik. “Action” komutu ile üye girişinin kontrolünü sağladık ve yolunu belirledik ve “method” komutu ile formumuzun post işlemini yaptık. “Required” komutu ile kullanıcı adı ve şifre bölümüne doldurma zorunluluğu koyduk. Giris.php sayfasını controller dosyamızın yardımı ile model tarafına işlenmesini sağlıyoruz. Üye girişinin kontrolünü model dosyamızdaki uye_model sayfasıdan veri tabanı bağlantısını sağlıyoruz.

3.3. Hesap Oluşturma Ekranı


Şekil 3.6. Hesap Oluşturma Ekranı

Şekil 3.7. Hesap Oluşturma Kod Ekranı

HTML yardımı ile formumuzu oluşturduk. CSS kodları sayesinde tasarımımızı düzenledik. PHP ile hatalı veya eksik bilgi girişinde hata verilmesini sağladık. Kayıt işlemini projemizin model tarafından veri tabanı bağlantısını sağladık.

3.4. Kategori Ekranı


Şekil 3.8. Kategori Ekranı


Şekil 3.9. Kategori Ekranı

Şekil 3.10. Kategori Kod Ekranı

Kategori ekranımızı HTML ve CSS yardımıyla tasarladık. Kategorideki ürünlerimizin resimlerini veri tabanından çektik. Kategoride gösterilen ürünlerimizi controller yardımı ile sayfada gösterimini sağladık.

3.5. İletişim Ekranı


Şekil 3.11. İletişim Sayfa Ekranı

Şekil 3.12. İletişim Sayfası Kod Ekranı

İletişim sayfamızda HTML CSS ve PHP kullanarak sayfamızı tasarladık. Controller yardımı ile iletişim formumuzu model tarafına işledik. Model sayfamız sayesinde veri tabanı ile bağlantımızı sağladık.

3.6. Sepet Ekranı


Şekil 3.13. Sepet Ekranı


Şekil 3.14. Sepet Sayfası Kod Ekranı

Sepet Ekranımızı HTML CSS ve PHP yardımı ile sayfamızı tasarladık. Cookie oluşturarak sayfadan çıksak bile ürünün sepette kalmasını sağladık. Siparişi tamamlama işlemini model kullanarak yapıp sipariş tamamlanınca veri tabanına düşmesini sağladık. Ürünlerin sayfaya çekilmesini id ile sağlıyoruz.

3.7. Admin Paneli Giriş Ekranı

Şekil 3.15. Admin Paneli Giriş Ekranı


Şekil 3.16. Admin Paneli Giriş Kod Ekranı

Admin Panelimizin form ve tasarımını HTML ve CSS yardımı ile yaptık. Action komutu ile formumuzun yolunu belirledik. Method komutu ile post işlemini yaptık. Oturum bilgilerini saklamak ve oturumları yönetmek için Session kullandık.

3.8. Admin Paneli Ana Sayfa Ekranı

Şekil 3.17. Admin Paneli Ana Sayfa Ekranı


Şekil 3.18. Admin Paneli Ana Sayfa Ekranı

Şekil 3.19. Admin Paneli Ana Sayfa Ekranı


Şekil 3.20. Admin Paneli Ana Sayfa Kod Ekranı

Bu kısımda Üyelerimizin bilgilerine erişim sağlayabiliyoruz. Ürünlerin özelliklerini değiştirebiliyoruz. Yönetici atamaları yapabiliyoruz. Siparişleri kontrol edebiliyoruz. Sistem ayarlarından bakımımızı güncellememizi yapabiliyoruz. İade ve kargolama işlemleri gibi birçok işlemlerimizi yapabiliyoruz. Bu sayfamızı HTML ve CSS yardımı ile tasarladık. Controller sayfamız sayesinde model tarafına işlenmesini sağlayıp model sayfamız ile veri tabanı bağlantısını sağladık.

3.9. Admin Paneli Sipariş Yönetim Ekranı


Şekil 3.21. Admin Paneli Sipariş Yönetim Ekranı

Şekil 3.22. Admin Paneli Sipariş Yönetim Kod Ekranı

Bu sayfamızın tasarımı HTML ve CSS kullanarak oluşturuldu. Veri tabanına bağlı olarak çalışıyor veri tabanından siparişler bölümünü çekiyor. Bu bölümümüzde iade işlemleri kargo işlemleri yapılıyor. Veri tabanına model klasöründe admin_panel model dosyasından bağlanıyor.

3.10. Admin Paneli Kategori Yönetim Ekranı


Şekil 3.23. Admin Paneli Kategori Yönetim Ekranı

Şekil 3.24. Admin Paneli Kategori Yönetim Kod Ekranı

Bu sayfayı HTML ve CSS kullanarak oluşturduk. Bu sayfamızda kategoride güncelleme işlemlerini yapıyor.

3.11. Admin Paneli Üye Yönetim Ekranı


Şekil 3.25. Admin Paneli Üye Yönetim Ekranı


Şekil 3.26. Admin Paneli Üye Yönetim Kod Ekranı

Bu sayfamızında tasarımını HTML ve CSS kullanarak oluşturdum. Veri tabanından üyelerimizi çekiyoruz. Bu sayfada üyelerimizi görebiliyoruz güncellemelerini yapabiliyoruz.

3.12. Admin Paneli Ürün Yönetim Ekranı

Şekil 3.27. Admin Paneli Ürün Yönetim Ekranı


Şekil 3.28. Admin Paneli Ürün Yönetim Kod Ekranı

Sayfamızı HTML ve CSS yardımı ile düzenledik. Veri tabanından ürünlerimizi çekiyoruz sayfamıza. Bu sayfamızda ürün güncellemesi gibi işlemler yapılıyor.

3.13. Admin Paneli Muhasebe Ekranı

Şekil 3.29. Admin Paneli Muhasebe Ekranı


Şekil 3.30. Admin Paneli Muhasebe Kod Ekranı

Bu sayfamızın tasarımını HTML ve CSS kullanarak oluşturduk. Verilerimizi veri tabanından çekiyoruz. Bu sayfamızda satışlarımızı karşımıza getiriyoruz. Banka bilgilerimizi güncelleyebiliyoruz.

3.14. Admin Paneli Yönetici Yönetim Ekranı

Şekil 3.31. Admin Paneli Yönetici Yönetim Ekranı


Şekil 3.32. Admin Paneli Yönetici Yönetim Kod Ekranı

Bu sayfamızda yönetici ekleyebiliyoruz. Yöneticinin yetkilerini düzenleyebiliyoruz. Eklediğimiz yönetici veri tabanımıza da düşüyor.

3.15. Admin Paneli Bülten Yönetim Ekranı


Şekil 3.33. Admin Paneli Bülten Yönetim Ekranı

Şekil 3.34. Admin Paneli Bülten Yönetim Kod Ekranı

Bu sayfada bültene kayıt olan kullanıcıları görebiliyoruz. Bültene kayıt ayrıyeten veri tabanımıza da düşüyor. Sayfamızın iskeletini HTML ile kurduk tasarımını CSS ile yaptık.

3.16. Veri Tabanı


Şekil 3.35. Veri Tabanı Ekranı

Şekil 3.36. Veri Tabanı Ekranı


Şekil 3.37. Veri Tabanı Ekranı

Projemizin veri tabanında 21 tablo bulunmaktadır. Veri tabanımızda üyeler, yönetim, ürünler, siparişler ve kategoriler gibi birçok tablo bulunmaktadır. Veri tabanımızı PDO ile oluşturduk PHP işlevlerini rahat çalıştırabilmek için ve daha güvenli olduğu için kullanımını sağladık. Üyelerin şifrelerini veri tabanına base64 şifrelemesi kullanarak kaydettik dışardan herhangi bir insan üyelerimizin şifrelerini görmemesini sağladık. Veri tabanı olarak MySQL veri tabanını kullandık.

4. SONUÇLAR

Projemiz online alışveriş sistemi yani kısaca E-Ticaret sitesi. Günümüzde internet dünyasının hızla gelişimiyle birlikte ve pandeminin de etkisiyle insanlar online alışveriş sistemine yönelmiştir. Zamandan tasarruf sağlamak için ve yorulmadan mağaza ve vitrin gezmemek için online alışveriş sistemi çok etkili bir hal almıştır. Bundan dolayı bende E-Ticaret sitesi yapmak istedim. Kendimi web alanında geliştirmek için bu projeyi yaparken HTML, CSS, Javascript ve PHP teknolojileri hakkında bilgi sahibi oldum. JQuery ve Bootstrap kütüphanelerini görmüş oldum. Veri tabanı olarak MySQLi öğrenmiş oldum.

KAYNAKLAR

1. Dünya Ticaretindeki Değişim Elektronik Ticaret ve İlk Adım KOBİ-NET: KOSGEB Avrupa Bilgi Merkezi.Haz.Meral Saym, Mustafa A.Fazlıoğlu,2000.Ankara

2. LEVY, Michael ve WEITZ, Barton A., (2001): Retailing Management, New York: McGraw-Hill Irwin.

3. GUPTA, Sunil ve CHATTARJEE Rabikar (1997): “Consumer and Corparation Adaptation of the World Wide Web as a Commercial Medium” Electronic Marketing and The Consumer, ed:Robert A.Peterson, SAGE Publications Com.,London, ss.123-138.

4. ROWLEY, Jennifer (1996): “Retailing and Shopping on the Internet”, International Journal of Retail and Distribution Management, Vol 24, No 3, ss.26–37.

5. BERMAN Barry ve EVANS Joel R. (2001): Retail Management A Strategic Approach, Prentice Hall, USA, 2001.

6. (https://www.mshowto.org/mvc-yapisi-ve-ozellikleri)

ÖZGEÇMİŞ

Mehmet Fatih ŞURGUN

Kişisel Bilgiler

Okul Numarası:

Doğum Tarihi:

Doğum Yeri:

İletişim Bilgileri

Telefon:

E-posta:

Adres:

Eğitim Durumu

Lise Öğrenimi:

Lisans Öğrenimi:

Yabancı Diller:

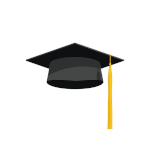
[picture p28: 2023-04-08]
web/web_design/panel/assets/img/grad.jpg

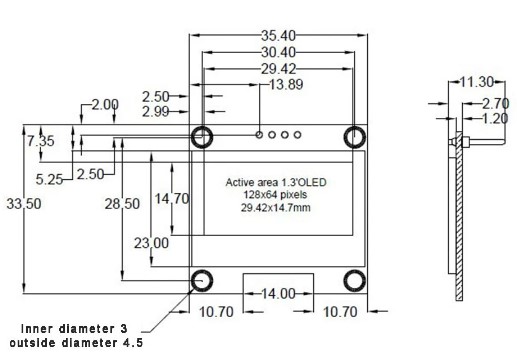
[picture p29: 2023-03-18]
diagrams/mechanical_draws/oled-board-size.jpg

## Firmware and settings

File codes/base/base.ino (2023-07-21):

// ===== OLED SETUP
//OLED icin gerekli olan kutuphanelerin import edilmesi
#include <SPI.h>
#include <Wire.h>
#include <Adafruit_GFX.h>
#include <Adafruit_SH110X.h>

//OLED'in I2C adresini tutan degisken
#define i2c_Address 0x3c 

// OLED olculerini tutan genislik ve yukseklik degiskenleri (piksel cinsinden)
#define SCREEN_WIDTH 128
#define SCREEN_HEIGHT 64

// OLED'in RESET pininin NodeMCU'ya baglandigi pin numarasi
// NOT: NodeMCU RESET butonunun pinini kullanmak icin '-1' verin.
#define OLED_RESET -1

Adafruit_SH1106G display = Adafruit_SH1106G(SCREEN_WIDTH, SCREEN_HEIGHT, &Wire, OLED_RESET);


// ===== WI-FI SETUP.
#include "ESP8266WiFi.h"

// WiFi parameters to be configured
const char* ssid = "TURKSAT-KABLONET-2.4G-tV1U";
const char* password = "JkVScMq8TGao";

// ====== CLIENT SETUP FOR HTTP REQUESTS
#include <ArduinoJson.h> //https://github.com/bblanchon/ArduinoJson
WiFiClient client; //Use WiFiClientSecure for HTTPS.
#define HOST "192.168.0.4" //host server
#define HOST_PORT 8080
#define TOKEN "derslik2cihaz"


// ===== RFID SETUP
#include <MFRC522.h>
MFRC522 rfid(0,16);//RFID Chip Select ve Reset pinlerinin ayarlarını yapıyoruz. 
boolean Yetki;

// ==== DEFINE BITMAPS FOR LOGOS

  //logoyu tutan HEX array
const unsigned char fuBitmap [] PROGMEM = {
	// 'logo, 50x50px
	0x00, 0x00, 0x00, 0x00, 0x00, 0x00, 0x00, 0x00, 0x00, 0x00, 0x00, 0x00, 0x00, 0x00, 0x00, 0x00, 
	0x00, 0x00, 0x00, 0x00, 0x00, 0x00, 0x00, 0x00, 0x00, 0x00, 0x00, 0x00, 0x1f, 0xff, 0xff, 0xff, 
	0xff, 0xfe, 0x00, 0x1f, 0xff, 0xff, 0xff, 0xff, 0xfe, 0x00, 0x1c, 0x00, 0x00, 0x30, 0x00, 0x0e, 
	0x00, 0x1c, 0x00, 0x00, 0x30, 0x00, 0x0e, 0x00, 0x1c, 0x00, 0x00, 0x30, 0x00, 0x0e, 0x00, 0x1c, 
	0x00, 0x00, 0x30, 0x00, 0x0e, 0x00, 0x1c, 0x00, 0x00, 0x30, 0x00, 0x0e, 0x00, 0x1c, 0x00, 0x00, 
	0x30, 0x00, 0x0e, 0x00, 0x1c, 0x00, 0x00, 0x30, 0x00, 0x0e, 0x00, 0x1c, 0x00, 0x00, 0x30, 0x00, 
	0x0e, 0x00, 0x1c, 0x00, 0x00, 0x30, 0x00, 0x0e, 0x00, 0x1c, 0x01, 0xfe, 0x30, 0x00, 0x0e, 0x00, 
	0x1c, 0x01, 0xfe, 0x30, 0x00, 0x0e, 0x00, 0x1c, 0x01, 0xfe, 0x30, 0x00, 0x0e, 0x00, 0x1c, 0x01, 
	0xfe, 0x30, 0x00, 0x0e, 0x00, 0x1c, 0x01, 0xfe, 0x30, 0x00, 0x0e, 0x00, 0x1c, 0x01, 0xfe, 0x3f, 
	0xff, 0xfe, 0x00, 0x1c, 0x01, 0xfe, 0x3f, 0xff, 0xfe, 0x00, 0x1c, 0x00, 0x00, 0x00, 0x00, 0x0e, 
	0x00, 0x1c, 0x00, 0x00, 0x00, 0x00, 0x0e, 0x00, 0x1c, 0x00, 0x00, 0x00, 0x00, 0x0e, 0x00, 0x1c, 
	0x00, 0x00, 0x00, 0x00, 0x0e, 0x00, 0x1c, 0x00, 0x00, 0x00, 0x00, 0x0e, 0x00, 0x1f, 0xff, 0xfe, 
	0x3f, 0xe0, 0x0e, 0x00, 0x1f, 0xff, 0xfe, 0x3f, 0xe0, 0x0e, 0x00, 0x1c, 0x00, 0x06, 0x3f, 0xe0, 
	0x0e, 0x00, 0x1c, 0x00, 0x06, 0x3f, 0xe0, 0x0e, 0x00, 0x1c, 0x00, 0x06, 0x3f, 0xe0, 0x0e, 0x00, 
	0x1c, 0x00, 0x06, 0x3f, 0xe0, 0x0e, 0x00, 0x1c, 0x00, 0x06, 0x3f, 0xe0, 0x0e, 0x00, 0x1c, 0x00, 
	0x06, 0x3f, 0xe0, 0x0e, 0x00, 0x1c, 0x00, 0x06, 0x00, 0x00, 0x0e, 0x00, 0x1c, 0x00, 0x06, 0x00, 
	0x00, 0x0e, 0x00, 0x1c, 0x00, 0x06, 0x00, 0x00, 0x0e, 0x00, 0x1c, 0x00, 0x06, 0x00, 0x00, 0x0e, 
	0x00, 0x1c, 0x00, 0x06, 0x00, 0x00, 0x0e, 0x00, 0x1c, 0x00, 0x06, 0x00, 0x00, 0x0e, 0x00, 0x1c, 
	0x00, 0x06, 0x00, 0x00, 0x0e, 0x00, 0x1c, 0x00, 0x06, 0x00, 0x00, 0x0e, 0x00, 0x1c, 0x00, 0x06, 
	0x00, 0x00, 0x0e, 0x00, 0x1f, 0xff, 0xff, 0xff, 0xff, 0xfe, 0x00, 0x1f, 0xff, 0xff, 0xff, 0xff, 
	0xfe, 0x00, 0x1f, 0xff, 0xff, 0xff, 0xff, 0xfe, 0x00, 0x00, 0x00, 0x00, 0x00, 0x00, 0x00, 0x00, 
	0x00, 0x00, 0x00, 0x00, 0x00, 0x00, 0x00, 0x00, 0x00, 0x00, 0x00, 0x00, 0x00, 0x00
};

static const unsigned char loadingBitmap [] PROGMEM = {
	0x00, 0x00, 0x03, 0xf0, 0x00, 0x80, 0x00, 0x00, 0x00, 0x3f, 0xff, 0x01, 0x80, 0x00, 0x00, 0x01, 
	0xff, 0xff, 0xe3, 0x80, 0x00, 0x00, 0x07, 0xff, 0xff, 0xff, 0x80, 0x00, 0x00, 0x0f, 0xff, 0xff, 
	0xff, 0x80, 0x00, 0x00, 0x3f, 0xff, 0xff, 0xff, 0x80, 0x00, 0x00, 0x7f, 0xff, 0xff, 0xff, 0x80, 
	0x00, 0x00, 0xff, 0xfe, 0x3f, 0xff, 0x80, 0x00, 0x01, 0xff, 0xe0, 0x03, 0xff, 0x80, 0x00, 0x03, 
	0xff, 0x00, 0x01, 0xff, 0x80, 0x00, 0x07, 0xfe, 0x00, 0x03, 0xff, 0x80, 0x00, 0x07, 0xfc, 0x00, 
	0x07, 0xff, 0x80, 0x00, 0x0f, 0xf8, 0x00, 0x00, 0x00, 0x08, 0x00, 0x0f, 0xf0, 0x00, 0xe0, 0x00, 
	0x3c, 0x00, 0x1f, 0xe0, 0x00, 0xe0, 0x00, 0x7c, 0x00, 0x1f, 0xc0, 0x00, 0xe0, 0x00, 0xfe, 0x00, 
	0x3f, 0xc0, 0x73, 0xfb, 0x80, 0xfe, 0x00, 0x3f, 0xc0, 0x7f, 0xff, 0xc0, 0xff, 0x00, 0x3f, 0x80, 
	0x7f, 0xff, 0x80, 0x7f, 0x00, 0x3f, 0x80, 0x3f, 0xff, 0x00, 0x7f, 0x00, 0x7f, 0x80, 0x3f, 0xff, 
	0x00, 0x7f, 0x80, 0x7f, 0x00, 0x7e, 0x1f, 0x80, 0x3f, 0x80, 0x7f, 0x00, 0x7c, 0x0f, 0x80, 0x3f, 
	0x80, 0x7f, 0x03, 0xfc, 0x0f, 0xf0, 0x3f, 0x80, 0x7f, 0x03, 0xfc, 0x0f, 0xf0, 0x3f, 0x80, 0x7f, 
	0x03, 0xfc, 0x0f, 0xf0, 0x3f, 0x80, 0x7f, 0x00, 0x7e, 0x1f, 0x80, 0x3f, 0x80, 0x7f, 0x80, 0x7f, 
	0xff, 0x00, 0x7f, 0x80, 0x7f, 0x80, 0x3f, 0xff, 0x00, 0x7f, 0x80, 0x3f, 0x80, 0x7f, 0xff, 0x80, 
	0x7f, 0x00, 0x3f, 0xc0, 0x7f, 0xff, 0x80, 0xff, 0x00, 0x3f, 0xc0, 0x77, 0xf3, 0x80, 0xff, 0x00, 
	0x1f, 0xc0, 0x60, 0xe1, 0x01, 0xfe, 0x00, 0x1f, 0xe0, 0x00, 0xe0, 0x01, 0xfe, 0x00, 0x1f, 0xe0, 
	0x00, 0xe0, 0x03, 0xfc, 0x00, 0x0f, 0xc0, 0x00, 0x00, 0x07, 0xfc, 0x00, 0x0f, 0x80, 0x00, 0x00, 
	0x0f, 0xf8, 0x00, 0x07, 0x00, 0x3c, 0x00, 0x1f, 0xf8, 0x00, 0x00, 0x1f, 0xf8, 0x00, 0x3f, 0xf0, 
	0x00, 0x00, 0x3f, 0xf0, 0x00, 0xff, 0xe0, 0x00, 0x00, 0x1f, 0xf0, 0x03, 0xff, 0xc0, 0x00, 0x00, 
	0x1f, 0xff, 0xff, 0xff, 0x80, 0x00, 0x00, 0x1f, 0xff, 0xff, 0xff, 0x00, 0x00, 0x00, 0x1f, 0xff, 
	0xff, 0xfe, 0x00, 0x00, 0x00, 0x1f, 0xff, 0xff, 0xf8, 0x00, 0x00, 0x00, 0x1f, 0xff, 0xff, 0xe0, 
	0x00, 0x00, 0x00, 0x1e, 0xff, 0xff, 0xc0, 0x00, 0x00, 0x00, 0x0c, 0x3f, 0xfe, 0x00, 0x00, 0x00, 
	0x00, 0x08, 0x00, 0x00, 0x00, 0x00, 0x00, 0x00, 0x00, 0x00, 0x00, 0x00, 0x00, 0x00
};

static const unsigned char rfidBitmap [] PROGMEM = {
	0x00, 0x00, 0x00, 0xff, 0x80, 0x00, 0x00, 0x00, 0x00, 0x0f, 0xff, 0xf0, 0x00, 0x00, 0x00, 0x00, 
	0x3f, 0xff, 0xfc, 0x00, 0x00, 0x00, 0x00, 0xff, 0xc1, 0xff, 0x00, 0x00, 0x00, 0x01, 0xfc, 0x00, 
	0x1f, 0x80, 0x00, 0x00, 0x03, 0xf0, 0x00, 0x07, 0xe0, 0x00, 0x00, 0x03, 0xc1, 0xff, 0x01, 0xf0, 
	0x00, 0x00, 0x03, 0x87, 0xff, 0xe0, 0xf8, 0x00, 0x00, 0x00, 0x1f, 0xff, 0xf8, 0x78, 0x00, 0x3f, 
	0xe0, 0x7f, 0x81, 0xfc, 0x3c, 0x00, 0x7f, 0xf0, 0x7c, 0x00, 0x3e, 0x1e, 0x00, 0x7f, 0xf0, 0x70, 
	0x18, 0x1f, 0x0e, 0x00, 0xf0, 0x00, 0x01, 0xff, 0x0f, 0x8f, 0x00, 0xe0, 0x00, 0x07, 0xff, 0xc7, 
	0xc7, 0x00, 0xe0, 0x00, 0x07, 0xff, 0xe3, 0xc7, 0x80, 0xe0, 0x00, 0x07, 0x81, 0xf1, 0xe3, 0x80, 
	0xe0, 0x00, 0x00, 0x00, 0x78, 0xe3, 0x80, 0xe0, 0x00, 0x00, 0x00, 0x3c, 0xe3, 0xc0, 0xe0, 0x00, 
	0x00, 0x3e, 0x3c, 0xf3, 0xc0, 0xe0, 0x00, 0x00, 0x7f, 0x1c, 0x71, 0xc0, 0xe0, 0x00, 0x00, 0xff, 
	0x1c, 0x71, 0xc0, 0xe0, 0x00, 0x00, 0xff, 0x9e, 0x71, 0xc0, 0xe0, 0x00, 0x00, 0xff, 0x1e, 0x71, 
	0xc0, 0xe0, 0x00, 0x00, 0xff, 0x1c, 0x71, 0xc0, 0xe0, 0x00, 0x00, 0x7e, 0x1c, 0x71, 0xc0, 0xe0, 
	0x00, 0x00, 0x3c, 0x3c, 0xf3, 0xc0, 0xe0, 0x00, 0x00, 0x00, 0x3c, 0xf3, 0x80, 0xe0, 0x00, 0x00, 
	0x00, 0x38, 0xe3, 0x80, 0xe0, 0x00, 0x00, 0x00, 0x39, 0xe7, 0x80, 0xe0, 0x00, 0x00, 0x00, 0x01, 
	0xc7, 0x80, 0xe0, 0x00, 0x00, 0x00, 0x03, 0xcf, 0x00, 0xe0, 0x00, 0x00, 0x00, 0x03, 0x8f, 0x00, 
	0xe0, 0x00, 0x00, 0x00, 0x03, 0x9e, 0x00, 0xe0, 0x00, 0x00, 0x00, 0x00, 0x3e, 0x00, 0xe0, 0x00, 
	0x00, 0x00, 0x00, 0x3c, 0x00, 0xe3, 0xf1, 0xf9, 0xbf, 0x80, 0x38, 0x00, 0xe3, 0xf9, 0xf9, 0xbf, 
	0xc0, 0x00, 0x00, 0xe3, 0x99, 0x81, 0xb8, 0xe0, 0x00, 0x00, 0xe3, 0x99, 0x81, 0xb0, 0x63, 0x80, 
	0x00, 0xe3, 0xf9, 0xf1, 0xb0, 0x63, 0x80, 0x00, 0xe3, 0xf1, 0xf1, 0xb0, 0x63, 0x80, 0x00, 0xe3, 
	0xb1, 0x81, 0xb8, 0xe3, 0x80, 0x00, 0xe3, 0xb9, 0x81, 0xbf, 0xc3, 0x80, 0x00, 0xe3, 0x99, 0x81, 
	0xbf, 0x83, 0x80, 0x00, 0xe0, 0x00, 0x00, 0x00, 0x03, 0x80, 0x00, 0xe0, 0x00, 0x00, 0x00, 0x03, 
	0x80, 0x00, 0xf0, 0x00, 0x00, 0x00, 0x07, 0x80, 0x00, 0x7f, 0xff, 0xff, 0xff, 0xff, 0x00, 0x00, 
	0x7f, 0xff, 0xff, 0xff, 0xff, 0x00, 0x00, 0x1f, 0xff, 0xff, 0xff, 0xfc, 0x00, 0x00
};

static const unsigned char wirelessBitmap [] PROGMEM = {
	0x00, 0x00, 0x00, 0x00, 0x00, 0x00, 0x00, 0x00, 0x00, 0x00, 0x00, 0x00, 0x00, 0x00, 0x00, 0x00, 
	0x00, 0x00, 0x00, 0x00, 0x00, 0x00, 0x00, 0x00, 0x00, 0x00, 0x00, 0x00, 0x00, 0x00, 0x00, 0x00, 
	0x00, 0x00, 0x00, 0x00, 0x00, 0x0f, 0xfc, 0x00, 0x00, 0x00, 0x00, 0x01, 0xff, 0xff, 0xe0, 0x00, 
	0x00, 0x00, 0x0f, 0xff, 0xff, 0xfc, 0x00, 0x00, 0x00, 0x1f, 0xff, 0xff, 0xfe, 0x00, 0x00, 0x00, 
	0x7f, 0xff, 0xff, 0xff, 0x80, 0x00, 0x01, 0xff, 0xfe, 0x1f, 0xff, 0xe0, 0x00, 0x03, 0xff, 0x80, 
	0x00, 0x7f, 0xf0, 0x00, 0x0f, 0xfc, 0x00, 0x00, 0x0f, 0xf8, 0x00, 0x1f, 0xf0, 0x00, 0x00, 0x07, 
	0xfe, 0x00, 0x3f, 0xe0, 0x00, 0x00, 0x01, 0xff, 0x00, 0x7f, 0x80, 0x00, 0x00, 0x00, 0x7f, 0x80, 
	0xff, 0x00, 0x03, 0xf0, 0x00, 0x3f, 0xc0, 0xfe, 0x00, 0x3f, 0xff, 0x00, 0x1f, 0xc0, 0xfc, 0x01, 
	0xff, 0xff, 0xe0, 0x0f, 0xc0, 0xf8, 0x03, 0xff, 0xff, 0xf0, 0x07, 0xc0, 0x70, 0x0f, 0xff, 0xff, 
	0xfc, 0x03, 0x80, 0x00, 0x1f, 0xff, 0xff, 0xfe, 0x00, 0x00, 0x00, 0x3f, 0xe0, 0x01, 0xff, 0x00, 
	0x00, 0x00, 0x7f, 0x80, 0x00, 0x7f, 0x80, 0x00, 0x00, 0xff, 0x00, 0x00, 0x3f, 0xc0, 0x00, 0x00, 
	0xfc, 0x00, 0x00, 0x0f, 0xc0, 0x00, 0x00, 0xf8, 0x00, 0x00, 0x07, 0xc0, 0x00, 0x00, 0xf8, 0x00, 
	0xc0, 0x07, 0xc0, 0x00, 0x00, 0x70, 0x0f, 0xfc, 0x03, 0x80, 0x00, 0x00, 0x00, 0x3f, 0xff, 0x00, 
	0x00, 0x00, 0x00, 0x00, 0x7f, 0xff, 0x80, 0x00, 0x00, 0x00, 0x00, 0xff, 0xff, 0xc0, 0x00, 0x00, 
	0x00, 0x01, 0xff, 0xff, 0xe0, 0x00, 0x00, 0x00, 0x01, 0xfc, 0x0f, 0xe0, 0x00, 0x00, 0x00, 0x01, 
	0xf0, 0x03, 0xe0, 0x00, 0x00, 0x00, 0x00, 0xe0, 0x01, 0xc0, 0x00, 0x00, 0x00, 0x00, 0x00, 0x00, 
	0x00, 0x00, 0x00, 0x00, 0x00, 0x00, 0x00, 0x00, 0x00, 0x00, 0x00, 0x00, 0x00, 0xc0, 0x00, 0x00, 
	0x00, 0x00, 0x00, 0x01, 0xe0, 0x00, 0x00, 0x00, 0x00, 0x00, 0x03, 0xf0, 0x00, 0x00, 0x00, 0x00, 
	0x00, 0x03, 0xf0, 0x00, 0x00, 0x00, 0x00, 0x00, 0x03, 0xf0, 0x00, 0x00, 0x00, 0x00, 0x00, 0x01, 
	0xe0, 0x00, 0x00, 0x00, 0x00, 0x00, 0x00, 0xc0, 0x00, 0x00, 0x00, 0x00, 0x00, 0x00, 0x00, 0x00, 
	0x00, 0x00, 0x00, 0x00, 0x00, 0x00, 0x00, 0x00, 0x00, 0x00, 0x00, 0x00, 0x00, 0x00, 0x00, 0x00, 
	0x00, 0x00, 0x00, 0x00, 0x00, 0x00, 0x00, 0x00, 0x00, 0x00, 0x00, 0x00, 0x00, 0x00
};

static const unsigned char cardBitmap [] PROGMEM = {
	0x00, 0x00, 0x00, 0x00, 0x00, 0x00, 0x00, 0x00, 0x00, 0x03, 0xf0, 0x00, 0x00, 0x00, 0x00, 0x00, 
	0x07, 0xf8, 0x00, 0x00, 0x00, 0x00, 0x00, 0x07, 0xf8, 0x00, 0x00, 0x00, 0x00, 0x00, 0x7f, 0x3f, 
	0x80, 0x00, 0x00, 0x00, 0x00, 0xfe, 0x1f, 0xc0, 0x00, 0x00, 0x00, 0x00, 0xfe, 0x1f, 0xc0, 0x00, 
	0x00, 0x1f, 0xff, 0xff, 0x3f, 0xff, 0xfe, 0x00, 0x7f, 0xff, 0xff, 0xff, 0xff, 0xff, 0x80, 0x7f, 
	0xff, 0xff, 0xff, 0xff, 0xff, 0x80, 0xff, 0xff, 0xff, 0xff, 0xff, 0xff, 0xc0, 0xf0, 0x00, 0xff, 
	0xff, 0xc0, 0x03, 0xc0, 0xf0, 0x00, 0x7f, 0xff, 0x80, 0x03, 0xc0, 0xf0, 0x00, 0x00, 0x00, 0x00, 
	0x03, 0xc0, 0xf0, 0x00, 0x00, 0x00, 0x00, 0x03, 0xc0, 0xf0, 0x00, 0x00, 0x00, 0x00, 0x03, 0xc0, 
	0xf0, 0x1f, 0x00, 0x00, 0x00, 0x03, 0xc0, 0xf0, 0x3f, 0x80, 0xff, 0xff, 0xe3, 0xc0, 0xf0, 0x3f, 
	0x80, 0xff, 0xff, 0xe3, 0xc0, 0xf0, 0x3f, 0x80, 0x00, 0x00, 0x03, 0xc0, 0xf0, 0x3f, 0x80, 0x00, 
	0x00, 0x03, 0xc0, 0xf0, 0x3f, 0x80, 0x00, 0x00, 0x03, 0xc0, 0xf0, 0x1f, 0x80, 0x00, 0x00, 0x03, 
	0xc0, 0xf0, 0x1f, 0x00, 0xff, 0xff, 0xe3, 0xc0, 0xf0, 0x00, 0x00, 0xff, 0xff, 0xe3, 0xc0, 0xf0, 
	0x3b, 0x80, 0x00, 0x00, 0x03, 0xc0, 0xf0, 0xfb, 0xe0, 0x00, 0x00, 0x03, 0xc0, 0xf0, 0xfb, 0xe0, 
	0x00, 0x00, 0x03, 0xc0, 0xf1, 0xfb, 0xf0, 0x00, 0x00, 0x03, 0xc0, 0xf1, 0xfb, 0xf0, 0xff, 0xff, 
	0xe3, 0xc0, 0xf1, 0xfb, 0xf0, 0xff, 0xff, 0xe3, 0xc0, 0xf1, 0xfb, 0xf0, 0x00, 0x00, 0x03, 0xc0, 
	0xf0, 0x00, 0x00, 0x00, 0x00, 0x03, 0xc0, 0xf0, 0x00, 0x00, 0x00, 0x00, 0x03, 0xc0, 0xf0, 0x00, 
	0x00, 0x00, 0x00, 0x03, 0xc0, 0xf8, 0x00, 0x00, 0x00, 0x00, 0x07, 0xc0, 0x7f, 0xff, 0xff, 0xff, 
	0xff, 0xff, 0x80, 0x7f, 0xff, 0xff, 0xff, 0xff, 0xff, 0x80, 0x1f, 0xff, 0xff, 0xff, 0xff, 0xfe, 
	0x00, 0x00, 0x00, 0x00, 0x00, 0x00, 0x00, 0x00
};

static const unsigned char xBitmap [] PROGMEM = {
	0x00, 0x00, 0x0f, 0xfc, 0x00, 0x00, 0x00, 0x00, 0x00, 0xff, 0xff, 0xc0, 0x00, 0x00, 0x00, 0x03, 
	0xff, 0xff, 0xf0, 0x00, 0x00, 0x00, 0x0f, 0xff, 0xff, 0xfc, 0x00, 0x00, 0x00, 0x1f, 0xe0, 0x01, 
	0xfe, 0x00, 0x00, 0x00, 0x7f, 0x80, 0x00, 0x7f, 0x80, 0x00, 0x00, 0xfe, 0x00, 0x00, 0x1f, 0xc0, 
	0x00, 0x01, 0xf8, 0x00, 0x00, 0x07, 0xe0, 0x00, 0x03, 0xf0, 0x00, 0x00, 0x03, 0xf0, 0x00, 0x07, 
	0xe0, 0x00, 0x00, 0x01, 0xf8, 0x00, 0x07, 0xc0, 0x00, 0x00, 0x00, 0xf8, 0x00, 0x0f, 0x80, 0x00, 
	0x00, 0x00, 0x7c, 0x00, 0x1f, 0x00, 0x00, 0x00, 0x00, 0x3e, 0x00, 0x1e, 0x03, 0x80, 0x00, 0x70, 
	0x1e, 0x00, 0x3e, 0x07, 0xc0, 0x00, 0xf8, 0x1f, 0x00, 0x3c, 0x07, 0xe0, 0x01, 0xf8, 0x0f, 0x00, 
	0x7c, 0x07, 0xf0, 0x03, 0xf8, 0x0f, 0x80, 0x78, 0x03, 0xf8, 0x07, 0xf0, 0x07, 0x80, 0x78, 0x01, 
	0xfc, 0x0f, 0xe0, 0x07, 0x80, 0x78, 0x00, 0xfe, 0x1f, 0xc0, 0x07, 0x80, 0xf0, 0x00, 0x7f, 0x3f, 
	0x80, 0x03, 0xc0, 0xf0, 0x00, 0x3f, 0xff, 0x00, 0x03, 0xc0, 0xf0, 0x00, 0x1f, 0xfe, 0x00, 0x03, 
	0xc0, 0xf0, 0x00, 0x0f, 0xfc, 0x00, 0x03, 0xc0, 0xf0, 0x00, 0x07, 0xf8, 0x00, 0x03, 0xc0, 0xf0, 
	0x00, 0x07, 0xf8, 0x00, 0x03, 0xc0, 0xf0, 0x00, 0x0f, 0xfc, 0x00, 0x03, 0xc0, 0xf0, 0x00, 0x1f, 
	0xfe, 0x00, 0x03, 0xc0, 0xf0, 0x00, 0x3f, 0xff, 0x00, 0x03, 0xc0, 0xf0, 0x00, 0x7f, 0x3f, 0x80, 
	0x03, 0xc0, 0x78, 0x00, 0xfe, 0x1f, 0xc0, 0x07, 0x80, 0x78, 0x01, 0xfc, 0x0f, 0xe0, 0x07, 0x80, 
	0x78, 0x03, 0xf8, 0x07, 0xf0, 0x07, 0x80, 0x3c, 0x07, 0xf0, 0x03, 0xf8, 0x0f, 0x00, 0x3c, 0x07, 
	0xe0, 0x01, 0xf8, 0x0f, 0x00, 0x3e, 0x07, 0xc0, 0x00, 0xf8, 0x1f, 0x00, 0x1e, 0x03, 0x80, 0x00, 
	0x70, 0x1e, 0x00, 0x1f, 0x00, 0x00, 0x00, 0x00, 0x3e, 0x00, 0x0f, 0x80, 0x00, 0x00, 0x00, 0x7c, 
	0x00, 0x07, 0xc0, 0x00, 0x00, 0x00, 0xf8, 0x00, 0x07, 0xe0, 0x00, 0x00, 0x01, 0xf8, 0x00, 0x03, 
	0xf0, 0x00, 0x00, 0x03, 0xf0, 0x00, 0x01, 0xf8, 0x00, 0x00, 0x07, 0xe0, 0x00, 0x00, 0xfe, 0x00, 
	0x00, 0x1f, 0xc0, 0x00, 0x00, 0x7f, 0x80, 0x00, 0x7f, 0x80, 0x00, 0x00, 0x1f, 0xf0, 0x03, 0xfe, 
	0x00, 0x00, 0x00, 0x0f, 0xff, 0xff, 0xfc, 0x00, 0x00, 0x00, 0x03, 0xff, 0xff, 0xf0, 0x00, 0x00, 
	0x00, 0x00, 0x7f, 0xff, 0x80, 0x00, 0x00, 0x00, 0x00, 0x0f, 0xfc, 0x00, 0x00, 0x00
};

static const unsigned char tickBitmap [] PROGMEM = {
	0x00, 0x00, 0x00, 0x00, 0x00, 0x00, 0x00, 0x00, 0x00, 0x1f, 0xf0, 0x00, 0x00, 0x00, 0x00, 0x00, 
	0xff, 0xff, 0x00, 0x00, 0x00, 0x00, 0x07, 0xff, 0xff, 0xc0, 0x00, 0x00, 0x00, 0x0f, 0xff, 0xff, 
	0xf0, 0x0c, 0x00, 0x00, 0x3f, 0xfc, 0x3f, 0xf8, 0x1e, 0x00, 0x00, 0x7f, 0x80, 0x03, 0xfe, 0x3f, 
	0x00, 0x00, 0xfe, 0x00, 0x00, 0x7e, 0x7f, 0x80, 0x01, 0xf8, 0x00, 0x00, 0x3c, 0xff, 0xc0, 0x03, 
	0xf0, 0x00, 0x00, 0x09, 0xff, 0xc0, 0x07, 0xe0, 0x00, 0x00, 0x03, 0xff, 0x80, 0x0f, 0xc0, 0x00, 
	0x00, 0x07, 0xff, 0x00, 0x0f, 0x80, 0x00, 0x00, 0x0f, 0xfe, 0x00, 0x1f, 0x00, 0x00, 0x00, 0x1f, 
	0xfc, 0x00, 0x3e, 0x00, 0x00, 0x00, 0x3f, 0xf8, 0x00, 0x3e, 0x00, 0x00, 0x00, 0x7f, 0xf0, 0x00, 
	0x3c, 0x00, 0x00, 0x00, 0xff, 0xe4, 0x00, 0x7c, 0x00, 0x00, 0x01, 0xff, 0xcc, 0x00, 0x78, 0x01, 
	0x80, 0x03, 0xff, 0x9e, 0x00, 0x78, 0x03, 0xc0, 0x07, 0xff, 0x3e, 0x00, 0xf8, 0x07, 0xe0, 0x0f, 
	0xfe, 0x1e, 0x00, 0xf8, 0x0f, 0xf0, 0x1f, 0xfc, 0x1e, 0x00, 0xf8, 0x0f, 0xf8, 0x3f, 0xf8, 0x1e, 
	0x00, 0xf0, 0x0f, 0xfc, 0x7f, 0xf0, 0x1e, 0x00, 0xf0, 0x07, 0xfe, 0xff, 0xe0, 0x1e, 0x00, 0xf0, 
	0x03, 0xff, 0xff, 0xc0, 0x1e, 0x00, 0xf8, 0x01, 0xff, 0xff, 0x80, 0x1e, 0x00, 0xf8, 0x00, 0xff, 
	0xff, 0x00, 0x1e, 0x00, 0xf8, 0x00, 0x7f, 0xfe, 0x00, 0x1e, 0x00, 0x78, 0x00, 0x3f, 0xfc, 0x00, 
	0x3e, 0x00, 0x78, 0x00, 0x1f, 0xf8, 0x00, 0x3e, 0x00, 0x7c, 0x00, 0x0f, 0xf0, 0x00, 0x3c, 0x00, 
	0x7c, 0x00, 0x07, 0xe0, 0x00, 0x7c, 0x00, 0x3e, 0x00, 0x03, 0xc0, 0x00, 0x7c, 0x00, 0x3e, 0x00, 
	0x01, 0x80, 0x00, 0xf8, 0x00, 0x1f, 0x00, 0x00, 0x00, 0x00, 0xf8, 0x00, 0x1f, 0x80, 0x00, 0x00, 
	0x01, 0xf0, 0x00, 0x0f, 0x80, 0x00, 0x00, 0x03, 0xf0, 0x00, 0x07, 0xc0, 0x00, 0x00, 0x07, 0xe0, 
	0x00, 0x07, 0xe0, 0x00, 0x00, 0x0f, 0xc0, 0x00, 0x03, 0xf8, 0x00, 0x00, 0x1f, 0x80, 0x00, 0x01, 
	0xfc, 0x00, 0x00, 0x7f, 0x00, 0x00, 0x00, 0xff, 0x00, 0x01, 0xfe, 0x00, 0x00, 0x00, 0x7f, 0xe0, 
	0x0f, 0xfc, 0x00, 0x00, 0x00, 0x1f, 0xff, 0xff, 0xf8, 0x00, 0x00, 0x00, 0x0f, 0xff, 0xff, 0xe0, 
	0x00, 0x00, 0x00, 0x01, 0xff, 0xff, 0x80, 0x00, 0x00, 0x00, 0x00, 0x7f, 0xfc, 0x00, 0x00, 0x00, 
	0x00, 0x00, 0x00, 0x00, 0x00, 0x00, 0x00, 0x00, 0x00, 0x00, 0x00, 0x00, 0x00, 0x00
};

static const unsigned char serverBitmap [] PROGMEM = {
	// 'logo, 50x50px
	0x00, 0x00, 0x00, 0x00, 0x00, 0x00, 0x00, 0x00, 0x00, 0x00, 0x00, 0x00, 0x00, 0x00, 0x00, 0x00, 
	0x00, 0x00, 0x00, 0x00, 0x00, 0x00, 0x00, 0x00, 0x00, 0x00, 0x00, 0x00, 0x00, 0x00, 0x00, 0x00, 
	0x00, 0x00, 0x00, 0x00, 0x3f, 0xff, 0xff, 0xff, 0x00, 0x00, 0x00, 0x60, 0x00, 0x00, 0x01, 0x80, 
	0x00, 0x00, 0xc0, 0x00, 0x00, 0x00, 0xc0, 0x00, 0x00, 0xdf, 0xff, 0xff, 0xbe, 0xc0, 0x00, 0x01, 
	0x80, 0x00, 0x00, 0x00, 0x60, 0x00, 0x01, 0x80, 0x00, 0x00, 0x00, 0x60, 0x00, 0x03, 0x00, 0x00, 
	0x00, 0x00, 0x30, 0x00, 0x03, 0x00, 0x00, 0x00, 0x00, 0x30, 0x00, 0x06, 0x00, 0x00, 0x00, 0x00, 
	0x18, 0x00, 0x06, 0x00, 0x00, 0x00, 0x00, 0x18, 0x00, 0x06, 0x00, 0x00, 0x00, 0x00, 0x18, 0x00, 
	0x07, 0xff, 0xff, 0xff, 0xff, 0xf8, 0x00, 0x04, 0x00, 0x00, 0x00, 0x00, 0x08, 0x00, 0x04, 0x00, 
	0x00, 0x00, 0x00, 0x08, 0x00, 0x04, 0x00, 0x00, 0x00, 0x07, 0x08, 0x00, 0x04, 0x66, 0x66, 0x67, 
	0xcd, 0x88, 0x00, 0x04, 0x66, 0x66, 0x6f, 0xc9, 0x88, 0x00, 0x04, 0x00, 0x00, 0x40, 0x0f, 0x08, 
	0x00, 0x04, 0x00, 0x00, 0x00, 0x00, 0x08, 0x00, 0x06, 0x00, 0x00, 0x00, 0x00, 0x18, 0x00, 0x07, 
	0xff, 0xff, 0xff, 0xff, 0xf8, 0x00, 0x07, 0xff, 0xff, 0xff, 0xff, 0xf8, 0x00, 0x04, 0x00, 0x00, 
	0x00, 0x00, 0x08, 0x00, 0x04, 0x00, 0x00, 0x00, 0x06, 0x08, 0x00, 0x04, 0x66, 0x66, 0x40, 0x0f, 
	0x08, 0x00, 0x04, 0x66, 0x66, 0x6f, 0xc9, 0x88, 0x00, 0x04, 0x66, 0x66, 0x40, 0x0f, 0x08, 0x00, 
	0x04, 0x00, 0x00, 0x00, 0x06, 0x08, 0x00, 0x04, 0x00, 0x00, 0x00, 0x00, 0x08, 0x00, 0x07, 0xff, 
	0xff, 0xff, 0xff, 0xf8, 0x00, 0x07, 0xff, 0xff, 0xff, 0xff, 0xf8, 0x00, 0x06, 0x00, 0x00, 0x00, 
	0x00, 0x18, 0x00, 0x04, 0x00, 0x00, 0x00, 0x00, 0x08, 0x00, 0x04, 0x20, 0x04, 0x40, 0x0f, 0x08, 
	0x00, 0x04, 0x66, 0x66, 0x6f, 0xc9, 0x88, 0x00, 0x04, 0x66, 0x66, 0x67, 0xcd, 0x88, 0x00, 0x04, 
	0x00, 0x00, 0x00, 0x07, 0x08, 0x00, 0x04, 0x00, 0x00, 0x00, 0x00, 0x08, 0x00, 0x06, 0x00, 0x00, 
	0x00, 0x00, 0x18, 0x00, 0x03, 0xff, 0xff, 0xff, 0xff, 0xf0, 0x00, 0x00, 0x00, 0x00, 0x00, 0x00, 
	0x00, 0x00, 0x00, 0x00, 0x00, 0x00, 0x00, 0x00, 0x00, 0x00, 0x00, 0x00, 0x00, 0x00, 0x00, 0x00, 
	0x00, 0x00, 0x00, 0x00, 0x00, 0x00, 0x00, 0x00, 0x00, 0x00, 0x00, 0x00, 0x00, 0x00
};




void setup(){
  Serial.begin(9600);
  //OLED ekrani baslat.
  oledStart();
  delay(500);

  //RFID'yi baslat.
  rfidStart();
  delay(500);

  //Wi-Fi'ya baglan.
  connectWifi();
  delay(500);

  //Sunucuya test baglantisi at.
  pingRemoteHost();
  delay(2000);
}

// Kisi basarili bir sekilde tanindiysa bu fonksiyon calisir.
void viewTick(){
  display.clearDisplay();
  display.drawBitmap(39,0,tickBitmap,50,50,1);

  //Ekranda "TICK" goster.
  display.setTextSize(1);
  display.setTextColor(SH110X_WHITE);
  display.setCursor(10, 56); //imleci (10,56) koordinatina tasi.
  display.println("Yoklama alindi.");
  display.display();
}

// Kisi taninmadiysa bu fonksiyon calisir.
void viewX(){
  display.clearDisplay();
  display.drawBitmap(39,0,xBitmap,50,50,1);

  //Ekranda "X" goster.
  display.setTextSize(1);
  display.setTextColor(SH110X_WHITE);
  display.setCursor(10, 56); //imleci (10,56) koordinatina tasi.
  display.println("Bu derse katilamazsiniz!");
  display.display();
}


// Kart okutulmadigi anlarda calisacak fonksiyon.
void pressCardInfo(){
  display.clearDisplay();
  display.drawBitmap(39,0,cardBitmap,50,40,1);

  //Ekranda "KART LOGOSU" goster.
  display.setTextSize(1);
  display.setTextColor(SH110X_WHITE);
  display.setCursor(10, 56); //imleci (10,56) koordinatina tasi.
  display.println("Kartinizi okutunuz.");
  display.display();
}

// Wi-Fi'a baglan.
void connectWifi(){
  display.clearDisplay();
  display.drawBitmap(39,0,wirelessBitmap,50,50,1);

  //Ekrana "Wi-Fi'a baglaniliyor." yaz.
  display.setTextSize(1);
  display.setTextColor(SH110X_WHITE);
  display.setCursor(10, 56); //imleci (10,56) koordinatina tasi.
  display.println("Wi-Fi baglaniliyor.");
  display.display();

  WiFi.begin(ssid, password);
  while (WiFi.status() != WL_CONNECTED) {
     delay(500);
     Serial.print(".");
  }
  Serial.println("WiFi connected");
  // Print the IP address
  Serial.println(WiFi.localIP());
}

// SPI ile RFID'ye baglan ve kullaniciyi bilgilendir.
void rfidStart(){
  display.clearDisplay();
  display.drawBitmap(39,0,rfidBitmap,50,50,1);

  //Ekrana "RFID baslatiliyor." yaz.
  display.setTextSize(1);
  display.setTextColor(SH110X_WHITE);
  display.setCursor(10, 56); //imleci (10,56) koordinatina tasi.
  display.println("RFID baslatiliyor.");
  display.display();

  SPI.begin();
  rfid.PCD_Init();
}

// OLED ekrani baslat.
void oledStart(){
  //Display'e 0x3C adresinden I2C protokolu ile baglan.
  display.begin(i2c_Address, true);
  //Display buffer'ini temizle.
  display.clearDisplay();
  delay(2000);

  //Logoyu ekranda goster.
  display.drawBitmap(39,0,fuBitmap,50,50,1);

  //Ekrana "Firat Universitesi" yaz.
  display.setTextSize(1);
  display.setTextColor(SH110X_WHITE);
  display.setCursor(10, 56); //imleci (10,56) koordinatina tasi.
  display.println("Firat Universitesi");
  display.display();
}
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
void loop() {
  pressCardInfo();

  //RFID looping
  Yetki = true;
  if ( rfid.PICC_IsNewCardPresent()){ 
    if ( rfid.PICC_ReadCardSerial()){
      byte Kart[4];
      for (int i = 0; i < 4; i++){
        Kart[i]=rfid.uid.uidByte[i];
        Serial.println(Kart[i]);
      }
      makeHttpRequest(Kart);
    }
    Serial.println(Yetki);
    if(Yetki==false){
      viewX();
      delay(3000);
    }
    else{
      viewTick();
      delay(3000);
    }
  }
}

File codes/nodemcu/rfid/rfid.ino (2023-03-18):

#include <SPI.h> 
#include <MFRC522.h>

//const byte YESIL_LED = 3;
//const byte KIRMIZI_LED = 2;

MFRC522 rfid(0,16);//RFID Chip Select ve Reset pinlerinin ayarlarını yapıyoruz. 
byte Kart[4] = {19, 53, 19, 17}; // {53, 122, 201, 226} buraya kendi okuttuğunuz kartın ID numarasını yazmalısınız. 
boolean Yetki; 
void setup() 
{ 
  Serial.begin(9600); 
  //pinMode(KIRMIZI_LED, OUTPUT); 
  //pinMode(YESIL_LED, OUTPUT);
  SPI.begin();
  rfid.PCD_Init(); 
} 
void loop()
{ 
  Yetki = true;
  if ( rfid.PICC_IsNewCardPresent())
  { 
    if ( rfid.PICC_ReadCardSerial())
    { Serial.print("Okunan Kart ID: ");
     Serial.print(rfid.uid.uidByte[0]); 
     Serial.print(",");
     Serial.print(rfid.uid.uidByte[1]); 
     Serial.print(","); 
     Serial.print(rfid.uid.uidByte[2]); 
     Serial.print(","); 
     Serial.println(rfid.uid.uidByte[3]);
    } 
    for (int i = 0; i < 4; i++)   
      if (rfid.uid.uidByte[i] != Kart[i]){
          Yetki = false;      
          break;
      }    
        
    if (Yetki == true) 
    { 
      Serial.println("Yetki Onaylandi…"); 
      //digitalWrite(YESIL_LED, HIGH); 
      delay(1000); 
      //digitalWrite(YESIL_LED, LOW);
    } 
    else 
    {
      Serial.println("Yetki Onaylanmadi…"); 
      //digitalWrite(KIRMIZI_LED, HIGH);
      delay(1000);
      //digitalWrite(KIRMIZI_LED, LOW);
    } 
    rfid.PICC_HaltA(); 
  } 
}

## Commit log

2023-04-08 web design added.
    [rfid_oled_nodemcu.fzz]
2023-04-17 getLesson() API function developed for devices.
2023-07-28 clean UPDATE
    [rfid_oled_nodemcu.fzz]
